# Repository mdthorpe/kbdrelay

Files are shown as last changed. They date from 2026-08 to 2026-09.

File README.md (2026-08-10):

# kbdrelay — USB HID keyboard bridge

A transparent two-board bridge that lets any USB keyboard type into a target
device as if it were a plain USB 1.1 boot-protocol keyboard. Two cheap
single-USB-controller boards, joined by a short SPI harness.

- **KBD** — keyboard-facing board (USB **host**, SPI **master**). The keyboard
  plugs into it; it reads key events and forwards them.
- **TGT** — target-facing board (USB **device**, SPI **slave**). It plugs into
  the target machine and presents as a vanilla boot keyboard, replaying what
  KBD sends.

> Boards are named for what they face. "Sender/receiver" is banned vocabulary
> here — both boards send and receive over the bidirectional SPI link.

See [`spec.md`](spec.md) (what/why), [`plan.md`](plan.md) (how), and
[`tasks.md`](tasks.md) (build log / progress).

## Status

**v1 achieved on the bench** — typing crosses the bridge, Caps/Num Lock LEDs
round-trip, hot-plug recovers, and the whole chain was validated on a
**Commodore Amiga 1200 (1992)** via a USB keyboard adapter, with modern and
vintage keyboards. Verified: AC1–AC5 (see `tasks.md` for caveats).

## Hardware

- 2× **Waveshare ESP32-S3-Zero** (one KBD, one TGT).
- Onboard WS2812 status LED (GPIO21, **RGB** order).
- Power: KBD from a dedicated 5 V feed (bus power / USB-PD); TGT from the target
  machine's USB. **Grounds common; 5 V never merged** (FR5).
- Keyboard-power inrush needs a **bulk cap (~220–1000 µF) on KBD's 5 V**.

### SPI harness (wire same-name to same-name — SPI names encode direction)

| Signal | KBD (master)  | TGT (slave) | Notes |
|---|---|---|---|
| SCK | GPIO4 (GP4) | GPIO4 | 1 MHz |
| MOSI | GPIO5 (GP5) | GPIO5 | key reports, heartbeats → |
| MISO | GPIO6 (GP6) | GPIO6 | ← LED reports |
| CS | GPIO7 (GP7) | GPIO7 | |
| DATA_READY  | GPIO8 (in) | GPIO8 (out) | TGT signals a queued LED report |
| GND | GND | GND | common |

Put **~470 Ω (→2.2 kΩ recommended) in series** on each signal line — limits
backfeed between boards when one is unpowered (FR5.4) and tames ringing.

## Firmware

ESP-IDF **6.x** via **PlatformIO** (`framework = espidf`). Shared framing +
CRC lives in [`components/bridge_proto`](components/bridge_proto) (also unit-
tested on the host). One project, one env per firmware:

| env | board role | what it is |
|---|---|---|
| `kbd` | KBD | USB host → reads keyboard → SPI master forwards KEY_REPORTs |
| `tgt` | TGT | SPI slave → replays as boot keyboard; watchdog releases keys |
| `mock_kbd` | test | SPI-master stand-in (scaffold) |
| `mock_tgt` | test | SPI-slave stand-in (scaffold) |
| `native` | host | `bridge_proto` unit tests (no hardware) |

### SPI protocol

Fixed 12-byte frames, full-duplex: `SYNC(0xA5) TYPE SEQ PAYLOAD[8] CRC8`.
Types: `IDLE`, `KEY_REPORT` (KBD→TGT), `LED_REPORT` (TGT→KBD), `HEARTBEAT`.
KBD sends on key change or every 25 ms; TGT releases all keys if no valid frame
for 75 ms (FR4.1).

## Build / flash / test

```sh
make build ENV=kbd        # compile (kbd | tgt | mock_kbd | mock_tgt)
make upload ENV=kbd       # flash over USB-C (see flashing quirks below)
make monitor              # serial monitor on the USB-UART adapter
make test                 # host unit tests (native, no hardware)
make reconfigure ENV=kbd  # clean rebuild of one env
```

Toolchain: PlatformIO Core (Python 3.13 penv) + ESP-IDF 6.x, board def
`boards/waveshare_esp32_s3_zero.json` (the official platform doesn't ship it).

### S3-Zero flashing quirks

- **Download mode:** hold **RESET + BOOT**, release RESET, pause, release BOOT.
- **After flashing, physically reset** (unplug/replug or RESET) — a software
  reset over native USB does not boot the app.
- **Logs go over UART** (TX/RX pads, 3.3 V USB-UART adapter, 115200): the USB-C
  is used by the app (host on KBD, device on TGT), and USB-Serial/JTAG shares
  the S3's USB PHY. Console is forced to UART (`CONFIG_ESP_CONSOLE_UART_DEFAULT`).
- **Power-up order on the bench:** power TGT (into the target) before KBD.

## License

TBD.

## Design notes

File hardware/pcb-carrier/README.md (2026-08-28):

# kbdrelay carrier board (hardware)

Single-sided, through-hole KiCad carrier PCB that hosts two socketed Waveshare
ESP32-S3-Zero modules (KBD + TGT) and joins them into the kbdrelay bridge.

**v0.1 is shipped and hardware-verified** (tag `v0.1-board`). The
`pcb-carrier-board` spec is **closed as the v0.1 record** — do not amend it.
New work happens in the v0.2 spec.

| What | Where |
|---|---|
| **Board of record (v0.1, as etched)** | `kbdrelay-carrier/kbdrelay-carrier-v0.1.kicad_pcb` — hand-routed, 0 DRC errors, zero jumpers |
| Schematic (shared by both layouts) | `kbdrelay-carrier/kbdrelay-carrier.kicad_sch` — ERC clean |
| Superseded scripted layout | `kbdrelay-carrier/kbdrelay-carrier.kicad_pcb` — ⚠ 4 DRC errors, still has the dropped LED. **Never export fab output from it.** |
| v0.1 retrospective | [`RETRO-v0.1.md`](./RETRO-v0.1.md) |
| v0.1 spec (closed) | [`../../.specs/pcb-carrier-board/`](../../.specs/pcb-carrier-board/) |

## Layout / conventions

```
hardware/pcb-carrier/
├── kbdrelay-carrier/
│   ├── kbdrelay-carrier.kicad_sch          # the schematic (one, shared)
│   ├── kbdrelay-carrier-v0.1.kicad_pcb     # BOARD OF RECORD (hand-routed)
│   ├── kbdrelay-carrier-v0.1.kicad_pro
│   ├── kbdrelay-carrier.kicad_pcb/.kicad_pro  # superseded scripted layout
│   ├── symbols/kbdrelay.kicad_sym          # project-local symbols (S3-Zero)
│   ├── footprints/kbdrelay.pretty/         # project-local footprints (.kicad_mod)
│   └── sym-lib-table / fp-lib-table        # register the above via ${KIPRJMOD}
├── fab/gerbers/                            # kbdrelay-carrier-v0.1-*.gbr (as etched)
├── place.py / route.py                     # scripted layout (superseded by hand route)
├── bridge_risk.py / audit_gaps.py          # etch-gap audits
├── make_lcd_art.sh                         # LCD photoresist artwork
├── BOM.md                                 # bill of materials
├── BUILD.md                               # fab + assembly + bring-up notes
└── RETRO-v0.1.md                          # what v0.1 taught us
```

- Use **project-local libraries** (Project-scope in KiCad) so the design is
  self-contained for anyone who clones the repo.
- Board is **single copper layer** (bottom), all discretes **through-hole**.
  Jumper-link budget was ≤ ~8; **v0.1 shipped with zero** — the hand route needed
  none, at wider traces (1.0 mm) than the script ever managed.
- Firmware is unchanged from v1 (same S3-Zero pinout: SPI GP4–GP8, USB on the
  module USB-C, UART0 TX/RX pads, WS2812 on GPIO21).

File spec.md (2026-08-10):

# Spec: USB HID Keyboard Bridge

**Status:** Draft v0.3 · **Level:** Functional (what/why — no implementation choices here)

## Naming

- **KBD** — the keyboard-facing board. USB host; the keyboard plugs into it.
  (Formerly "receiver.")
- **TGT** — the target-facing board. USB device; it plugs into the target
  machine and presents as a keyboard. (Formerly "sender.")

Boards are named for what they face, which never inverts. "Sender/receiver"
is banned vocabulary in this project: both boards send and receive on the
bidirectional SPI link, so those words are ambiguous.

## Overview

A transparent two-board bridge that lets any USB keyboard type into a target
device as if it were a plain USB 1.1 boot-protocol keyboard.

- **KBD** reads key events from the keyboard and forwards them over SPI.
- **TGT** replays those events to the target as a minimal boot-protocol
  keyboard.

Primary motivation: two cheap single-USB-controller boards are simpler and
more cost-effective than one board with dual USB controllers, and the split
makes each half independently developable and testable.

## Constitution (project principles)

1. Cheapest commonly available parts that meet requirements; no unused capability.
2. Each board is independently developable and testable (SPI peer can be mocked).
3. Prefer boring, well-documented libraries and stacks over clever code.
4. Artifacts stay proportional to the problem: one spec, one plan, one task list.

## Functional Requirements

### FR1 — Keyboard input (KBD)
- **FR1.1** Accept exactly one USB keyboard, plugged directly into KBD.
- **FR1.2** Keyboards that internally enumerate as a hub + HID device MUST work.
  KBD's host stack must traverse one hub level to reach the keyboard
  interface. (Many modern keyboards are internally hub devices.)
- **FR1.3** Boot-protocol keyboard support (8 modifiers + 6-key rollover) is the
  fidelity bar. NKRO, media keys, and vendor extensions are out of scope; if a
  keyboard offers boot protocol, use it.
- **FR1.4** Keyboard hot-plug MUST work: unplug/replug at any time without
  restarting either board.

### FR2 — Bridge link (SPI)
- **FR2.1** Key events are forwarded KBD → TGT over SPI.
- **FR2.2** The link is bidirectional: HID output reports (LED state — Caps/Num/
  Scroll Lock) flow TGT → KBD and MUST reach the keyboard, so lock LEDs
  reflect the target's state.
- **FR2.3** Messages carry a type identifier. v1 defines types for (a) keyboard
  input report and (b) LED output report. The framing MUST allow new types to be
  added without breaking existing ones (future: synthetic/custom key events —
  see Design Considerations).
- **FR2.4** Message integrity MUST be verifiable (e.g., checksum); corrupt
  messages are dropped, never replayed as keystrokes.

### FR3 — Keyboard output (TGT)
- **FR3.1** TGT presents to the target as the most vanilla USB low-speed
  boot-protocol keyboard possible: single interface, no composite device, no
  extra endpoints. Reference bar: works on hosts that support only USB 1.1-era
  keyboards.
- **FR3.2** Reports from KBD are replayed transparently — no remapping,
  no filtering, no reordering.

### FR4 — Failure behavior
- **FR4.1** On keyboard disconnect, SPI link loss, or KBD power loss, TGT
  MUST release all keys (send an empty report) within **100 ms**. No
  stuck keys, ever.
- **FR4.2** Either board MUST tolerate the other being unpowered or absent
  indefinitely, and recover automatically when it returns.
- **FR4.3** TGT remains enumerated on the target even when the keyboard
  or KBD is absent — it never disconnects/reconnects on the USB bus, it
  simply types nothing. (To the target: a keyboard nobody is touching. Distinct
  from FR2.4, which governs dropping corrupt messages.)

### FR5 — Power
- **FR5.1** Each board has exactly ONE 5 V source, and two sources are never
  connected together. KBD is powered from a dedicated power-only USB feed
  ("bus power"). TGT is powered solely by the target machine's USB port.
- **FR5.2** KBD MUST supply 5 V VBUS to the keyboard port, with ≥ 250 mA
  guaranteed (covers any conventional keyboard). Power is routed through the
  dev board's normal power path (onboard connector); the actual ceiling
  therefore depends on the board's power-path components and MUST be
  documented in plan.md. High-draw RGB keyboards at full brightness are
  best-effort. (Future option: USB-C PD supply and/or direct-rail feed can
  raise the budget without spec changes.)
- **FR5.3** TGT receives VBUS from the target device; this MUST NOT backfeed
  into or conflict with bus power. The target's port is never asked to power
  anything beyond TGT itself (tens of mA).
- **FR5.4** Boards share ground via the SPI harness (all grounds in the
  system are common). Driving SPI lines into an unpowered peer MUST NOT
  damage or latch up either board.

### FR6 — Latency
- **FR6.1** Added end-to-end latency (keyboard event received by KBD →
  report available to target) ≤ **10 ms**, excluding USB polling intervals
  outside our control. Human typing speed is the use case; gaming is not.

## Out of Scope (v1)

- External hubs / multiple keyboards / mouse or other HID device classes
- NKRO, media keys, consumer-control pages, vendor-specific HID
- Key remapping, macros, synthetic events (noted below as a design consideration)
- Wireless anything
- Configuration UI of any kind

## Design Considerations (non-binding, informs plan.md)

- **Future synthetic events:** a later version may inject target-specific
  combinations (e.g., Fn+Key unique to the target device). FR2.3's typed message
  framing exists so this can be added as a new message type with no protocol
  break. Do not otherwise design for it.
- **SPI direction asymmetry:** SPI is master/slave and the slave cannot initiate
  transfers. The LED backchannel (FR2.2) will need a data-ready signal line or
  polling; the spec requires the behavior, not the mechanism.

## Acceptance Criteria

- **AC1** A plain boot-protocol keyboard and a hub-type keyboard both type
  correctly into the target, including modifiers and 6-key chords.
- **AC2** Caps Lock pressed on the keyboard toggles the target's caps state AND
  the keyboard's Caps Lock LED.
- **AC3** Holding a key and yanking the keyboard (or the SPI harness, or KBD
  power) releases the key on the target within 100 ms.
- **AC4** Keyboard replug and KBD power-cycle both recover to a working
  state with no interaction on the TGT/target side.
- **AC5** TGT enumerates and types correctly on a USB 1.1-era reference
  target.
- **AC6** Each board passes its tests standalone with the SPI peer mocked.

## Open Questions

- ~~Name a specific reference target device for AC5?~~ **RESOLVED:** v1 was
  validated against a **Commodore Amiga 1200 (1992) with a USB keyboard
  adapter**, using both modern and vintage USB keyboards. If a machine of that
  era accepts TGT, the boot-keyboard descriptor is effectively universal.

## Observations (v1 bring-up)

- **Numpad on nav/symbol keys (target-side limit):** numpad-only keyboards
  produce digits with Num Lock on, but the navigation/math-symbol *Keypad*
  usages don't reach the Amiga. HID keypad keys always send Keypad usages; the
  *host* maps them to digits vs arrows per Num Lock. The bridge replays
  keycodes verbatim (FR3.2), so this is the target adapter's interpretation,
  not a bridge fault. A future synthetic-event type (see Design Considerations)
  could remap if ever desired.

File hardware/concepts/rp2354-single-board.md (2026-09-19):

# Concept: single-board RP2354 kbdrelay

**Status: CONCEPT / SCRATCH — PARKED. Not a spec. No gates, no approvals, not
tracked in `.specs/`.**

> **Parked 2026-09-XX.** Assorted RP2350 dev boards ordered (see §7) to try the
> firmware path. Pick this back up when they arrive — start at §8 step 1.
> The active hardware effort remains `.specs/pcb-carrier-v0-2/`.
 This is a "what would we build with no inherited requirements"
sketch from a discussion on 2026-09-XX. Nothing here supersedes
`.specs/pcb-carrier-v0-2/`, which remains the real, active effort.

---

## 1. Premise

Throw away every constraint the current design inherited — two boards, an SPI
link, THT parts, home etching, the ESP32-S3 — and ask what the device actually
wants to be. Answer: **one chip, one board, no inter-board protocol.**

The ESP32-S3 forced the two-board architecture because it has a single USB OTG
controller: it can be host *or* device, not both. The RP2040/RP2350 family has a
hardware USB controller **plus** PIO, and `pico-pio-usb` bit-bangs a second
full-/low-speed USB port out of PIO state machines. One chip, two USB ports, no
bridge protocol at all.

### What this deletes

| Gone | Why |
|---|---|
| Second MCU | one chip has both PHYs |
| SPI link (SCK/MOSI/MISO/CS/DATA_READY) | no inter-board comms |
| 12-byte framing + CRC8 | ditto |
| 2.2 kΩ series resistors ×5 | ditto |
| Open-drain CS backfeed workaround | one rail, no peer to backfeed |
| Power-sequencing failure class entirely | one rail |
| Reverse-polarity Schottky D1 + its unmeasured ~0.3 V Vf | USB-C can't be reversed |
| PPTC F1 | replaced by an active current-limit switch |
| 470 µF bulk inrush cap | replaced by the switch's soft-start |
| UART console + BOOT/RESET flashing ritual | UF2 mass-storage bootloader |

### What it costs

A firmware rewrite, against a different USB stack, replacing code that is
verified on real hardware including a 1992 Amiga 1200. The bridge logic itself
is trivial (TinyUSB host HID → shared report buffer → TinyUSB device HID, ~300
lines), but the **descriptor-parsing keyboard detection** and **report dedup**
logic were paid for in bench time and have to be re-earned.

---

## 2. Core architecture (shared by both variants)

```
                  ┌──────────── RP2354A ────────────┐
 USB-A recept.    │                                 │   captive USB-A
 (keyboard)  ─────┤ PIO-USB host      native USB dev ├────── pigtail
   D+/D-          │ (2 consecutive     (hardware PHY)│       (target)
                  │  GPIO, 27R + 15k)               │
                  └─────────────────────────────────┘
```

**PHY assignment is deliberate and non-negotiable:** the *target* side gets the
hardware USB controller, because that is the side that must present as a
bulletproof vanilla USB 1.1 boot keyboard to a 1992 machine via an adapter. The
*keyboard* side gets PIO-USB, because that peer is swappable and observable.

**MCU: RP2354A** — RP2350 with 2 MB flash stacked in package. Drops the external
QSPI flash IC and its four routed traces. Dual Cortex-M33, 12 PIO state
machines. RP2040 + W25Q16 works identically and is ~$0.30 cheaper; RP2354A is
chosen for fewer parts and because learning the current chip is worth more than
learning the five-year-old one.

**Signal integrity:** this is USB **full speed, 12 Mbps**, rise times ~4–20 ns.
Controlled-impedance 90 Ω differential pairs and a 4-layer stackup are
*optional practice*, not a requirement. Every cheap USB dongle on earth is
2-layer. Keep pairs short, roughly matched, over unbroken ground, and stop
worrying. Hand-soldered pigtails are electrically fine at FS.

**Common parts:**

| Ref | Part | Note |
|---|---|---|
| U1 | RP2354A (QFN-60, 7×7) | 2 MB stacked flash |
| Y1 | 12 MHz crystal, 3225 | PIO-USB needs a 120/240 MHz sysclk multiple |
| U2 | AP2112K-3.3 LDO | MCU only, ~50 mA |
| U3 | TPS2051C / MIC2005 | keyboard-port current limit, soft-start, FAULT |
| D1,D2 | USBLC6-2SC6 ×2 | ESD, both ports |
| D3 | WS2812B | status; light pipe in the case |
| SW1,SW2 | BOOTSEL, RESET | pinholes in the case bottom |
| J1 | USB-A receptacle | keyboard |
| — | Tag-Connect TC2030 pads | SWD, underside |
| — | 2× UART test pads | console via CH340 dongle |
| — | 0402 passives | |

**Debug:** BOOTSEL gives UF2 drag-and-drop flashing over the native USB port —
unplug from the target, plug into a laptop, hold one button, drag a file. No
UART dance, no physical power-cycle. The USB CDC console is **not** available,
because the native port is busy being a keyboard and adding a composite CDC
interface would break the "vanilla boot keyboard" contract the Amiga adapter
depends on. Hence the UART pads, and hence SWD being worth the footprint —
stepping through TinyUSB enumeration beats printf by a wide margin.

**GPIO budget** is not close to tight: 2 for PIO-USB D+/D−, 1 VBUS sense, 1
TPS2051 EN, 1 FAULT, 1 WS2812, 2 UART, 1 mode strap, SWD dedicated. Break out 8
spare on a castellated edge or 1.27 mm header anyway.

---

## 3. Variant A — externally powered puck

**The chosen primary concept.**

### Power

```
USB-C 5V (5.1k CC pulldowns) ─┬─ AP2112K-3.3 ── RP2354A
                              └─ TPS2051C ───── USB-A VBUS (keyboard)

target VBUS ── divider ── GPIO   (SENSE ONLY, zero draw)
target D+/D-/GND ─────────────── native USB
```

The target side is a **self-powered USB device**: it takes D+/D−/GND and senses
VBUS through a divider, drawing exactly nothing from the target. Descriptor
reports self-powered, `bMaxPower = 0`.

⚠ **The one rule:** do not assert the D+ pull-up until VBUS is detected. Assert
it early and you back-power the host's bus through the pull-up, and the target
sees a phantom device while it's powered off. RP2350's native USB has VBUS
detect and TinyUSB handles this — it's a config item, not a design problem.

This is what makes the entire v0.1 backfeed saga (the 1.68 V latch, the
open-drain CS fix, the rejected bleeder resistors) structurally impossible:
there is one rail, and the target contributes nothing to it.

USB-C input over a barrel jack because it can't be inserted backwards (deleting
D1 and its Vf penalty), every phone charger is a valid supply, and 5.1 kΩ CC
pulldowns let you read the advertised current if you ever care.

Keyboard-port current limit can be set generously (~1.2–1.5 A) since the supply
is external. The TPS2051C's controlled slew-rate soft-start is the *correct*
fix for the high-inrush-keyboard brownout that the 470 µF cap was papering over,
and its FAULT pin gives a deterministic failure: LED goes red, log says
"keyboard exceeded limit", firmware can retry by toggling EN.

### Form factor

~45 × 30 × 12 mm block, two-part 3D-printed case, four M2 heat-set inserts.

- **Front edge:** USB-A receptacle (keyboard).
- **Rear edge:** captive USB-A male pigtail to target, plus USB-C power jack.
  Both cables leave rearward; the keyboard sits clean in front.
- **Front face:** RGB LED behind a light pipe.
- **Bottom:** BOOTSEL/RESET pinholes, SWD pads.

Silhouette matches the period-correct Amiga/PS2/ADB adapter dongles, which is
half the appeal. It reads as a piece of kit, not a dev board in a box.

**Pigtail assembly is self-service** — PCBWay won't attach cables. Put a 4-pad
2.54 mm footprint at the board edge with two slots either side for a zip-tie
strain relief; cut the end off a USB-A extension cable and solder
D+/D−/VBUS-sense/GND. A 4-pin JST-PH hidden inside the case is the detachable
alternative. Budget ~10 minutes and one moment of regret.

### Cost

BOM ~$4.50. Five assembled boards from PCBWay including setup/stencil/
engineering: **$120–150 total**, i.e. $25–30 each. Setup fees dominate at this
quantity; at qty 50 it'd be $10–15 each.

### Trade-off

Three cables. That's the honest cost of the always-externally-powered choice —
it buys total immunity from the power-sequencing bug class and unlimited
keyboard headroom, and it pays in desk clutter and a board that's dead without
a brick.

---

## 4. Variant B — 500 mA bus-powered stick

**Worth building too. Prettier object, tighter constraints.**

Drop the USB-C jack entirely. The whole device runs from the target's VBUS.

### Power

```
target VBUS ─┬─ AP2112K-3.3 ── RP2354A   (~40 mA)
             └─ TPS2051C ────── USB-A VBUS (keyboard, limit ~400 mA)
```

Now a **bus-powered** device: descriptor declares `bMaxPower = 250` (500 mA),
and it must draw ≤100 mA until configured — which it does comfortably, since
the bridge itself is ~40 mA and the keyboard port stays disabled (TPS2051 `EN`
low) until enumeration completes. That gating is mandatory, not optional.

### Power budget

| Load | Current |
|---|---|
| RP2354A @ 120 MHz + PIO-USB | ~35–40 mA |
| WS2812B (dim / single colour) | ~5–20 mA |
| Regulator + leakage | ~5 mA |
| **Available for keyboard** | **~430 mA** |

Reality check on what that covers:

| Device | Typical draw | Works? |
|---|---|---|
| Vintage / membrane keyboard | 20–50 mA | yes, trivially |
| Modern mechanical, no backlight | 50–100 mA | yes |
| Single-colour backlit | 100–250 mA | yes |
| RGB gaming keyboard | 300–500 mA | marginal to no |
| Keyboard with integrated USB hub | 500 mA+ | no |
| Game controller with rumble | 500 mA spikes | no |

So: **~80% of devices, and the excluded 20% is knowable in advance.** Set the
TPS2051C limit to ~400 mA with its ILIM resistor. A device over budget trips the
switch, FAULT asserts, LED goes red — a clean refusal at plug-in, not a
brownout thirty minutes into a session. That deterministic failure mode is the
entire reason the active switch is worth $0.40 over a PPTC.

**Open risk:** the target must actually supply 500 mA. A modern PC will. A 1992
A1200 via a USB-to-Amiga adapter is an unknown — depends entirely on that
adapter's regulator, and the A1200's own supply is a beefy linear unit so the
upstream side is probably fine. **This is the thing to measure first if Variant
B gets built.**

### Form factor

~35 × 18 × 10 mm — genuinely a USB stick. USB-A receptacle one end, captive
USB-A male pigtail the other (or a board-edge male plug, which needs a 2.0–2.4
mm board or a shim and turns it into something rigid hanging off the machine —
the pigtail is more practical). Two cables total, no brick, nothing to plug in.

### Cost

BOM ~$3.80. Same assembly economics as A.

### Trade-off

More elegant object, one fewer cable, no wall wart — and a device that silently
excludes a whole class of modern keyboards, plus an unverified assumption about
what the target port can source.

---

## 5. Variant comparison

| | A: externally powered | B: bus-powered |
|---|---|---|
| Cables | 3 (keyboard, target, power) | 2 |
| Size | ~45 × 30 × 12 mm puck | ~35 × 18 × 10 mm stick |
| Keyboard budget | ~1.2 A, essentially unlimited | ~430 mA |
| RGB / hub keyboards | yes | no |
| Works without a brick | no | yes |
| Unverified assumptions | none material | target port sources 500 mA |
| BOM | ~$4.50 | ~$3.80 |
| Failure mode | none expected | clean refusal via FAULT |

They share ~90% of the schematic. Building A first and B second is cheap;
building both in one PCBWay order is cheaper still, and directly answers the
"can the A1200 adapter actually feed this" question with hardware.

---

## 6. Deliberately excluded

**Full HID dev/lab tool** (capture, replay, descriptor dumping, protocol
fuzzing, OLED, broken-out GPIO banks). Products already exist for this. Not
worth building.

**Still open, and cheap to defer:** transparent-only versus a compiled-in
keymap remap table. Pure firmware. The interesting version is **layout
translation** — the Amiga adapter maps HID usages to Amiga scancodes
positionally, so a modern PC keyboard puts the wrong keys in the wrong places;
remapping in the bridge makes any keyboard an Amiga keyboard with no adapter
changes. Hardware cost is one GPIO mode strap, or just reuse BOOTSEL as a
runtime input. Wire the strap regardless and decide after the board boots.

---

## 7. Off-the-shelf shortcut — Waveshare RP2350-USB-A

**Found 2026-09-XX. This may make Variant B a firmware-only project.**

<https://www.waveshare.com/rp2350-usb-a.htm> — RP2350A, 2 MB flash, LDO 500 mA,
listed as *"with PIO-USB Type-A and USB Type-C port"*. Under $10. That is a
native USB device port **and** a PIO-USB Type-A host receptacle on one
off-the-shelf board — i.e. the entire Variant B topology, already built.

The PHY assignment falls out correct: **native hardware USB on the Type-C →
target** (via a C-to-A cable), **PIO-USB on the Type-A receptacle → keyboard**.
That matches §2's non-negotiable split exactly.

Sibling products, for reference:

| Board | Ports | Fit |
|---|---|---|
| **RP2350-USB-A** | PIO-USB Type-A host + native Type-C | **the one** |
| RP2350-USB-C (`sku=34641`/`34953`) | PIO-USB on a Type-C, female or male | needs an A-to-C adapter for the keyboard; worse for no gain |
| RP2350-One | Type-A male, single port | USB-stick form factor, only one port |
| RP2350-PiZero | native Type-C + PIO-USB port + DVI/TF | works, but far more board than needed |

**RP2354 is a non-issue here.** Stacked flash was only ever a part-count
optimisation on a board *we* lay out. On a module someone else assembled, an
external W25Q is two parts we never touch.

### Check these on the schematic PDF before ordering

These decide whether "add external power" is a jumper or a trace cut:

1. **Is the Type-A port's VBUS tied straight to Type-C VBUS, with any current
   limit?** Almost certainly a direct tie with no limiting. That means a greedy
   keyboard browns out the MCU — precisely the failure the TPS2051C exists to
   prevent. Fine for an experiment, not for a thing you actually use.
2. **Is there a broken-out 5 V/VBUS pad, and a diode between it and the
   Type-C?** If there's no diode, injecting external 5 V there **back-drives
   VBUS onto the target's port** — the exact bug class v0.1 spent months on.
   Adding external power would mean cutting the VBUS trace and feeding
   downstream of the cut. Doable, ugly, and it turns a clean dev board into a
   bodge.
3. **CC pulldowns on the Type-C.** Near-certain since it's a device port, but
   confirm if the plan is ever to power it from a charger.

No ESD protection on either port, obviously. Irrelevant at this price.

### Consequence for this concept

Buy one and prove the firmware first (see §8). If it works and 500 mA covers
the keyboards you care about, **you may simply be done** and never need a
custom board at all. If the power ceiling bites, the answer is the custom
Variant A board — *not* a VBUS bodge on a dev board.

---

## 8. Breadboard / prototyping path

Nothing here needs a fabbed board to validate. The whole architecture can be
proven on off-the-shelf parts first, and **should be** — specifically the
PIO-USB hub and low-speed handling, which is where the bring-up risk is
concentrated.

Cheapest credible rigs, roughly in order of convenience:

| Option | What it is | Note |
|---|---|---|
| **Waveshare RP2350-USB-A** | RP2350 + PIO-USB Type-A host + native Type-C | see §7 — this *is* Variant B, not just a rig for it |
| Adafruit Feather RP2040 **with USB Type A Host** (#5723) | RP2040 + a real USB-A host port already wired to PIO with the 27 Ω/15 k network | closest thing to the concept in a dev board; just add power |
| Adafruit RP2040/RP2350 board + **USB Host BFF / Stemma host breakout** | host port as an add-on | flexible, works with RP2350 for the actual target chip |
| Pico 2 (RP2350) + USB-A breakout + 2× 27 Ω + 2× 15 kΩ | fully manual | cheapest, ~$8 total, and you learn the host-port network properly |
| Waveshare RP2040-PiZero | has a USB-A host port | fine, less documented for PIO-USB |

Software: `pico-pio-usb` + TinyUSB, either the Pico SDK directly or the Arduino
core (`arduino-pico` bundles both and has working host-HID examples). Validate
in this order:

1. Enumerate one plain keyboard over PIO-USB, print reports to UART/SWD.
2. Simultaneously present as a boot keyboard over native USB to a laptop.
3. Pass keystrokes end to end. This is the whole product.
4. **Low-speed keyboard** over PIO-USB (the vintage ones).
5. **Hubbed / composite keyboard** — the known-weak case.
6. Measure actual current draw of the bridge, and of each keyboard you own, to
   settle Variant B's budget with numbers instead of a table of guesses.
7. If an A1200 is to hand: measure what the USB adapter will source. That single
   number decides whether Variant B is real.

Only after 1–5 pass is there any point ordering a board.

---

## 9. Provenance

Discussion-only, outside the spec process, at the user's explicit request. The
active hardware effort remains `.specs/pcb-carrier-v0-2/` (two-board ESP32-S3
carrier, PCBWay 2-layer, THT discretes, 3D-printed case). Nothing in this file
is approved, gated, or scheduled.

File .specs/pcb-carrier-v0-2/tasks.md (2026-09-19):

# PCB Carrier Board v0.2 Tasks

Spec: `pcb-carrier-v0-2`  
Status: tasks-draft  
Created: 2026-08-29  
Brainstorm: `./brainstorm.md`
Requirements: `./requirements.md`
Design: `./design.md`

## Implementation Plan

Ordered PCB tasks, each traceable to requirement IDs, each with a concrete
"done when". New KiCad project at `hardware/pcb-carrier-v0.2/`; **no v0.1 file is
touched** — v0.1 is frozen at tag `v0.1-board`.

> ⚠ **T-002 is a hard gate on T-005.** Per design decision D-004, the power-path
> measurement happens on a breadboard **before** layout, not at bring-up. If it
> fails, the correct response is to return to the design gate — or the
> requirements gate if the fix is a supply above 5.00 V, which contradicts D-003.
> Do not begin layout on the strength of the budget arithmetic alone. That is
> exactly the mistake v0.1 made (retro F-8).

- [ ] 1. Project, design rules, and libraries
  - ID: T-001
  - Requirement(s): NFR-001, NFR-002, NFR-006, NFR-011
  - Files/areas: `hardware/pcb-carrier-v0.2/` (new KiCad project),
    `kbdrelay-carrier-v0.2.kicad_dru`, `sym-lib-table`, `fp-lib-table`
  - Work: create the KiCad project with version in the filename; vendor
    PCBWay's rules as the project-local `.kicad_dru` with the **2-layer 1 oz**
    rule block active and the others left commented; set board stackup to
    2 layers; register the project-local S3-Zero symbol/footprint library.
    Confirm the seven stock footprints named in design.md resolve.
  - Validation: `kicad-cli pcb drc` runs and *enforces* the vendored rules —
    prove enforcement with a temporary canary rule that must fail, then remove
    it. A rules file that silently fails to load is worse than none.
  - Done when: empty board DRCs clean against PCBWay rules, canary proved
    enforcement, all footprint references resolve.

- [ ] 2. **GATE** — Breadboard power-path validation
  - ID: T-002
  - Requirement(s): FR-013, FR-014, FR-017, FR-018, NFR-014
  - Files/areas: bench; results recorded in `design.md` and
    `hardware/pcb-carrier-v0.2/MEASUREMENTS.md`
  - Work: build `J1 → F1 → D1(shunt) → C1/C2 → module VDD` on a breadboard with
    the real parts. At **exactly 5.00 V** input and a **500 mA** load at the
    keyboard port, measure and record all three: voltage at the jack, at
    U1.VDD, and at keyboard VBUS. **The unknown being measured is the module's
    internal VDD→VBUS drop** — the ~0.255 V of budget nobody has ever checked.
    Then: apply reverse polarity and confirm D1 conducts, F1 trips, and normal
    operation resumes once corrected with nothing replaced. Also confirm a
    high-inrush keyboard enumerates first try with C1 fitted.
  - Validation: keyboard VBUS ≥ 4.40 V at 500 mA from 5.00 V in, **measured and
    written down**, not inferred.
  - Done when: the measurement is recorded and either (a) VBUS ≥ 4.40 V, so
    layout may proceed, or (b) it is short, and the fallback chain in design.md
    §Risks is worked in order — swap F1 to Littelfuse 60R090 for +0.055 V, else
    return to the requirements gate on D-003. **Recording a failure and
    proceeding anyway is not an acceptable outcome.**

- [ ] 3. Schematic capture
  - ID: T-003
  - Requirement(s): FR-006, FR-007, FR-008, FR-011, FR-012, FR-015, FR-020,
    FR-021, FR-022, NFR-004, NFR-007
  - Files/areas: `hardware/pcb-carrier-v0.2/kbdrelay-carrier-v0.2.kicad_sch`
  - Work: capture the net list in design.md §Schematic Design exactly. All five
    SPI lines through R1–R5 on the GP4–GP8 mapping; common GND; power chain
    J1→F1→D1→C1/C2→U1.VDD with D1 as a **shunt** (cathode to rail, anode to
    GND) and F1 **upstream** of D1; both UART headers through R6–R9 with **no
    supply pin**; **U2.VDD carrying an explicit no-connect flag** so ERC records
    the 5 V isolation as intentional. Every part gets a value and a footprint.
  - Validation: `kicad-cli sch erc` → **zero violations** (AC-10, ERC half).
  - Done when: ERC is clean, U2.VDD is explicitly no-connect, and no net joins
    the two 5 V domains.

- [ ] 4. BOM and sourcing verification
  - ID: T-004
  - Requirement(s): NFR-004, NFR-005, NFR-006
  - Files/areas: `hardware/pcb-carrier-v0.2/BOM.md`
  - Work: generate the BOM from the schematic. For each of the twelve
    non-module line items, confirm the MPN is **currently in stock at one
    distributor** and record the ordering part number. Confirm every part is
    through-hole and that only the module uses a hand-built footprint.
  - Validation: a single cart at one distributor covers every non-module line
    item (AC-12).
  - Done when: BOM is generated from the schematic rather than hand-written,
    every MPN is confirmed orderable, and any substitution is recorded.

- [ ] 5. Two-layer layout *(blocked by T-002)*
  - ID: T-005
  - Requirement(s): FR-003, FR-004, FR-016, NFR-002, NFR-003, NFR-008, NFR-016
  - Files/areas: `hardware/pcb-carrier-v0.2/kbdrelay-carrier-v0.2.kicad_pcb`
  - Work: place U1/U2 at opposite board edges with USB-C over the 1.5 mm
    overhang notch; J1 on the front edge near U1; power cluster between them;
    R1–R5 mid-board. Route **signals on F.Cu only**, leaving **B.Cu as an
    uninterrupted ground pour** — the structural fix for v0.1's split pour.
    Minimise outline subject to iron access (NFR-003 vs NFR-016; NFR-016 wins).
    Silkscreen `5V ⏜ centre +` at J1, plus the version identifier. Verify
    nothing obstructs either module's BOOT/RESET buttons.
  - Validation: `kicad-cli pcb drc` against the vendored PCBWay rules → **zero
    violations** (AC-10, DRC half); a `pcbnew` script fills zones and asserts
    the GND net resolves to **exactly one** connected region with zero
    unconnected items (AC-11).
  - Done when: DRC clean, ground verified as a single region **by script and not
    by eye**, buttons unobstructed, outline measured and recorded.

- [ ] 6. Fabrication package and build documentation
  - ID: T-006
  - Requirement(s): NFR-010, NFR-011, NFR-012, NFR-013
  - Files/areas: `hardware/pcb-carrier-v0.2/fab/`, `BUILD.md`, `README.md`,
    an as-built extraction script
  - Work: export Gerbers and drill to **exactly one** canonical directory, with
    the version in every filename. Write `BUILD.md` for a builder with no prior
    knowledge: order, assemble in a stated sequence, bring up, and how to tell
    it works. Write the script that extracts the as-built table (outline, track
    widths, clearances, layer count, footprint count) **from the board file**, so
    no as-built number is ever restated by hand (NFR-013).
  - Validation: Gerbers render correctly in an independent viewer; the as-built
    script output matches the board; no fab output exists anywhere else in the
    tree.
  - Done when: the package is orderable without opening KiCad, and every
    as-built figure in the docs is script-generated.

- [ ] 7. Order and assemble
  - ID: T-007
  - Requirement(s): FR-002, NFR-005, NFR-016
  - Files/areas: physical hardware; notes to `BUILD.md`
  - Work: order boards from PCBWay and parts from the verified BOM. Assemble
    following `BUILD.md` **as written**, recording every place the
    documentation was wrong or insufficient.
  - Validation: assembly completes with no undocumented step; every joint was
    reachable with a conventional iron with neighbours already fitted (AC-15).
  - Done when: at least one board is populated, `BUILD.md` is corrected from
    real experience, and any NFR-016 violation is recorded even if tolerable.

- [ ] 8. Bare-board bring-up *(no modules seated)*
  - ID: T-008
  - Requirement(s): FR-007, FR-008, FR-012, FR-013, FR-014, FR-015, NFR-014
  - Files/areas: physical board; results to `MEASUREMENTS.md`
  - Work: continuity on all five SPI lines through their series resistors;
    GND common; **confirm the barrel-jack rail reaches U1's socket only and
    U2's 5 V socket pin is isolated**. Apply 5.00 V and measure the protected
    rail. Apply **reverse polarity deliberately** and confirm F1 trips with no
    damage and self-recovers. Short the keyboard port briefly and confirm F1
    trips and recovers. Measure F1's in-circuit resistance.
  - Validation: all isolation, polarity and overcurrent checks pass with no
    modules fitted (AC-3, AC-4, AC-5, AC-6).
  - Done when: every check passes and **every measured value is written down**,
    not just observed.

- [ ] 9. Populated bring-up and acceptance
  - ID: T-009
  - Requirement(s): FR-001, FR-004, FR-009, FR-010, FR-017, FR-018, FR-020,
    FR-021, FR-022, NFR-014
  - Files/areas: physical board + two S3-Zero modules running v1 firmware
  - Work: seat both modules; **reflash in situ using the modules' own
    BOOT/RESET buttons** with the board assembled (AC-2). Measure and record
    loaded keyboard VBUS with the highest-draw keyboard available — this is the
    on-board confirmation of the T-002 breadboard figure. Test **all** power-up
    orderings, especially KBD-first with TGT cold. Connect a powered USB-UART
    adapter to an **unpowered** module and confirm no damage; confirm the debug
    headers carry no supply voltage. Reproduce the v1 acceptance tests AC1–AC5:
    typing, Caps/Num LED backchannel, hot-plug recovery, watchdog.
  - Validation: AC-1, AC-2, AC-7, AC-8, AC-9, AC-13 all pass, with the VBUS
    figure recorded.
  - Done when: the bridge works on v0.2 hardware and the recorded VBUS
    measurement either confirms or corrects the T-002 prediction. **A
    discrepancy between breadboard and board is a finding to write up, not a
    rounding error to ignore.**

- [ ] 10. Reproduction check and spec close-out
  - ID: T-010
  - Requirement(s): NFR-012, NFR-013, NFR-014
  - Files/areas: `BUILD.md`, `README.md`, `design.md`, this file,
    `AGENTS.md`, `~/.pi/memory-md/kbdrelay/core/HARDWARE.md`
  - Work: verify a board can be built from the repo documentation alone
    (AC-14). Regenerate the as-built table from the final board file and confirm
    every documented figure matches. Fold the recorded measurements into
    `design.md` so the accepted risks are either closed or restated with
    evidence. Update `AGENTS.md` and the durable hardware notes. Tag the
    release.
  - Validation: no documented as-built figure differs from the board file; no
    acceptance criterion is left unrecorded.
  - Done when: the spec reads as a true account of what was built — the thing
    v0.1 failed at, requiring a retroactive reconstruction.

## Verification Checklist

- [x] Requirements IDs are referenced by tasks. All 20 FR and 14 NFR appear in
      at least one task.
- [x] Design testing strategy is represented by tasks. Its eight gates map to
      T-002 (breadboard), T-003 (ERC), T-004 (BOM), T-005 (DRC + ground),
      T-008 (bare board), T-009 (populated + system), T-010 (reproduction).
- [x] Each task has a clear validation command or manual check.
- [x] Rollback/migration tasks are included when applicable. **N/A by
      construction** — new hardware in a new directory; v0.1 is frozen at tag
      `v0.1-board` and no v0.1 file is modified. Firmware is unchanged, so both
      board revisions run identical binaries.

## Execution Notes

- Keep `Status: tasks-draft` until the user explicitly approves this task plan.
- After approval, change status to `tasks-approved` and run
  implementation-readiness validation before starting work.
- **T-002 gates T-005.** Layout must not begin before the breadboard
  measurement is recorded. T-003 and T-004 may proceed in parallel with T-002,
  since the net list does not depend on the measured value — only the choice of
  F1 does, and a substitution there is a value change, not a topology change.
- Record deviations from design in `design.md` **before** implementing them.
- Measurements are recorded when taken (NFR-014). An unrecorded measurement
  counts as not having happened — this is the v0.1 failure mode this spec is
  built to avoid.
- Where an automated attempt fails, record it as a limitation of that attempt,
  never as a proof of impossibility. Two such claims were made during v0.1 and
  both were later disproved by hand.
- The `make test` hook covers host firmware unit tests and is **not relevant to
  these tasks** — firmware is unchanged. PCB tasks are hardware-verified.

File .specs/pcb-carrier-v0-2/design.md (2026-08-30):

# PCB Carrier Board v0.2 Design

Spec: `pcb-carrier-v0-2`  
Status: design-approved  
Created: 2026-08-29  
Brainstorm: `./brainstorm.md`
Requirements: `./requirements.md`

## Summary

A two-layer, through-hole carrier PCB that sockets two Waveshare ESP32-S3-Zero
modules and joins them into the kbdrelay bridge. The board provides the five-wire
SPI interconnect with series protection, a common ground, a protected 5 V feed to
the KBD module only, and two debug UART headers. Three connectors reach the
outside world at board edges: each module's own USB-C, plus a 2.1 × 5.5 mm barrel
jack for power.

The single most consequential design decision is the **reverse-polarity
topology**, and it is settled by arithmetic rather than preference. FR-018 allows
a total of 0.60 V from the jack to the keyboard port at 500 mA. A series Schottky
(v0.1's answer) consumes roughly 0.40 V of that on its own, and the best
acceptable PPTC consumes another 0.29 V — **0.69 V, over budget before any copper
is drawn**. A shunt crowbar diode consumes **zero volts** in normal operation and
delivers the same protection, so v0.2 uses a shunt crowbar. This is the clearest
possible demonstration that v0.1's power path could not have met v0.2's
requirements, which is what a clean sheet is for.

One term in that budget has never been measured by anyone: the drop *inside* the
S3-Zero module, from its VDD pin to the VBUS pin of its USB-C connector. It could
plausibly be anywhere from a few millivolts of copper to a full Schottky drop if
the module carries a backfeed-blocking diode. Everything downstream of the
protection choice depends on it, so **D-004 makes measuring it a precondition for
layout**, not a bring-up surprise.

## Goals and Non-Goals

### Goals

- Meet the FR-018 voltage budget with measured evidence, not arithmetic alone
  (FR-018, D-004).
- Protect against reverse polarity at zero steady-state voltage cost (FR-013,
  FR-014).
- Produce a board manufacturable by PCBWay's standard 2-layer 1 oz service with
  zero DRC violations against their published rules (NFR-001, NFR-002).
- Make every non-module part orderable from one distributor by MPN (NFR-005),
  using stock KiCad footprints wherever one exists (NFR-006).
- Guarantee a single continuous ground region by construction and verify it
  (NFR-008).
- Keep documentation derivable from the board files rather than restated
  (NFR-013).

### Non-Goals

- Overvoltage protection. Deliberately excluded per EC-002.
- Any enclosure consideration beyond edge-mounted connectors (D-005).
- Firmware or pin-mapping changes (DC-001).
- Reuse of any v0.1 artifact (Overview, Out of Scope).

## Architecture

Three electrically distinct domains share one ground. The KBD domain is fed and
protected by this board; the TGT domain is powered entirely by the target machine
and this board deliberately supplies it nothing but ground and signals.

```mermaid
flowchart LR
  PSU["5V PSU<br/>2.1x5.5mm centre +"] --> J1["J1 barrel jack<br/>board edge"]
  J1 -->|"+5V_IN"| F1["F1 PPTC<br/>resettable overcurrent"]
  F1 -->|"+5V_PROT"| CROW["D1 shunt Schottky<br/>cathode to rail, anode to GND<br/>0V drop when correct"]
  CROW --> BULK["C1 470uF + C2 100nF<br/>inrush reservoir"]
  BULK -->|"+5V_KBD"| U1["U1 = KBD module<br/>ESP32-S3-Zero"]
  U1 -->|"internal VDD to VBUS<br/>UNMEASURED"| KBUSB["U1 USB-C<br/>board edge"]
  KBUSB --> KB["USB keyboard<br/>via A-to-C adapter"]

  U1 <-->|"SPI x5 through R1-R5<br/>GP4 GP5 GP6 GP7 GP8"| U2["U2 = TGT module<br/>ESP32-S3-Zero"]
  U1 --- GND(("common GND"))
  U2 --- GND

  U2 -->|"USB device"| TGUSB["U2 USB-C<br/>board edge"]
  TGUSB --> TGT["target machine<br/>supplies U2's only 5V"]

  U1 -->|"TX RX through R6 R7"| JD1["J2 debug UART KBD<br/>no supply pin"]
  U2 -->|"TX RX through R8 R9"| JD2["J3 debug UART TGT<br/>no supply pin"]

  X["U2 VDD: NOT CONNECTED<br/>keeps the 5V domains separate"] -.-> U2
```

## Power Path Design

### Topology

```
J1.tip (+5V_IN) ── F1 (PPTC) ──┬── D1 cathode        ── C1 ── C2 ──┬── U1.VDD
                               │   (D1 anode to GND)               │
J1.sleeve ──────────────────── GND ────────────────────────────────┘
```

`D1` is reverse-biased and electrically invisible during normal operation. Under
reverse polarity it conducts, `F1` heats and trips, and the fault collapses to a
trickle; correcting the supply restores normal operation with nothing replaced
(FR-013, FR-014). `F1` must sit **upstream** of `D1` — that ordering is what lets
it interrupt the fault. `F1` simultaneously serves as the keyboard overcurrent
protection (FR-015), because U1 is the only load on the rail, so one part does
both jobs.

### Voltage budget (FR-018)

Allowance is 0.60 V total, from 5.00 V at the jack to 4.40 V at the keyboard
port, at 500 mA (D-003).

| Term | Worst case @ 500 mA | Basis |
|---|---|---|
| Barrel jack contact | ~0.015 V | typical contact resistance |
| F1 PPTC | **0.290 V** | Bel 0ZRE0100FF1A, R₁max 0.58 Ω (post-trip worst case; 0.22 Ω initial gives 0.110 V fresh) |
| D1 shunt crowbar | **0.000 V** | reverse-biased in normal operation |
| Board copper | ~0.020 V | short, wide 1 oz traces |
| Module socket contacts | ~0.020 V | two contacts in the path |
| **Subtotal on the carrier** | **~0.345 V** | |
| **Remaining for U1 internal VDD→VBUS** | **~0.255 V** | **UNMEASURED — see D-004** |

Rejected alternative, for the record:

| Topology | Protection drop @ 500 mA | Verdict |
|---|---|---|
| Series 1N5817 + 0ZRE0100 | 0.40 + 0.29 = **0.69 V** | **Fails FR-018** before copper |
| Series SB540 + 0ZRE0100 | ~0.30 + 0.29 = **0.59 V** | Fails once copper and sockets are added |
| **Shunt crowbar + 0ZRE0100** | **0.29 V** | **Selected** |

### PPTC selection trade-off

The Littelfuse 60R090 used in v0.1 is electrically *better* than the Bel Fuse
alternatives, but requires the hand-built footprint v0.1 created because the
stock Bourns footprint staggers its pads for kinked leads.

| Part | Hold | R₁max | Drop @ 500 mA | Stock KiCad footprint |
|---|---|---|---|---|
| Littelfuse 60R090 | 0.90 A | 0.47 Ω | 0.235 V | ✗ (hand-built) |
| **Bel 0ZRE0100FF1A** | **1.00 A** | **0.58 Ω** | **0.290 V** | ✓ `Fuse_BelFuse_0ZRE0100FF_L18.7mm_W5.1mm` |
| Bel 0ZRE0075FF1A | 0.75 A | 0.84 Ω | 0.420 V | ✓ |

**Selected: Bel 0ZRE0100FF1A**, preferring NFR-006's stock footprint at a cost of
0.055 V. The 0ZRE0075 is rejected outright — 0.42 V leaves nothing for the module.
If the D-004 breadboard shows the module's internal drop is large, the fallback is
to switch to the 60R090 and reinstate the hand-built footprint, buying back
0.055 V. A 0.5 A-class PPTC is not considered: v0.1 established that it derates to
roughly 0.42 A at 40 °C and would nuisance-trip a legal 500 mA keyboard.

### Inrush

`C1` = 470 µF electrolytic, `C2` = 100 nF ceramic, both immediately upstream of
U1.VDD (FR-017). This is the validated fix for the keyboard-inrush brownout
observed on v1 hardware (DC-008) and is carried forward deliberately.

## Schematic Design

### Net list

| Net | Members |
|-----|---|
| `+5V_IN` | J1.tip, F1.1 |
| `+5V_PROT` | F1.2, D1.K, C1.+, C2.1, U1.VDD |
| `GND` | J1.sleeve, D1.A, C1.−, C2.2, U1.GND, U2.GND, J2.3, J3.3 |
| `SPI_SCK_K` / `SPI_SCK_T` | U1.GP4 → R1 → U2.GP4 |
| `SPI_MOSI_K` / `SPI_MOSI_T` | U1.GP5 → R2 → U2.GP5 |
| `SPI_MISO_K` / `SPI_MISO_T` | U1.GP6 → R3 → U2.GP6 |
| `SPI_CS_K` / `SPI_CS_T` | U1.GP7 → R4 → U2.GP7 |
| `SPI_DRDY_K` / `SPI_DRDY_T` | U1.GP8 → R5 → U2.GP8 |
| `UART_K_TX` / `UART_K_RX` | U1.TX → R6 → J2.1; U1.RX → R7 → J2.2 |
| `UART_T_TX` / `UART_T_RX` | U2.TX → R8 → J3.1; U2.RX → R9 → J3.2 |
| *(no net)* | **U2.VDD — explicitly no-connect (FR-012)**; U1/U2 3V3 and GPIO1,2,3,9,10,11,12,13 |

`U2.VDD` carries an explicit no-connect flag in the schematic so ERC records the
isolation as intentional rather than as an omission.

### Bill of materials

All through-hole (NFR-004). Modules are exempt from the sourcing rule (DC-007).

| Ref | Qty | Value / MPN | Footprint | Purpose / requirement |
|-----|-----|---|---|---|
| U1, U2 | 2 | Waveshare ESP32-S3-Zero | `kbdrelay:ESP32-S3-Zero-Socketed` (project lib) | KBD and TGT (FR-001) |
| — | 4 | 1×9 female header 2.54 mm | part of module footprint | sockets (FR-002) |
| — | 4 | 1×9 male header 2.54 mm | — | soldered into module pad rows |
| J1 | 1 | CUI **PJ-102AH** (2.1 × 5.5 mm) | `Connector_BarrelJack:BarrelJack_CUI_PJ-102AH_Horizontal` | 5 V input (FR-011) |
| F1 | 1 | Bel Fuse **0ZRE0100FF1A** | `Fuse:Fuse_BelFuse_0ZRE0100FF_L18.7mm_W5.1mm` | overcurrent + crowbar interrupt (FR-015) |
| D1 | 1 | **1N5822** (3 A / 40 V Schottky) | `Diode_THT:D_DO-201AD_P12.70mm_Horizontal` | shunt crowbar (FR-013, FR-014) |
| C1 | 1 | 470 µF / 16 V electrolytic | `Capacitor_THT:CP_Radial_D10.0mm_P5.00mm` | inrush reservoir (FR-017) |
| C2 | 1 | 100 nF ceramic disc | `Capacitor_THT:C_Disc_D5.0mm_W2.5mm_P5.00mm` | HF decoupling |
| R1–R5 | 5 | 2.2 kΩ 1/4 W | `Resistor_THT:R_Axial_DIN0207_L6.3mm_D2.5mm_P10.16mm_Horizontal` | SPI series (FR-008) |
| R6–R9 | 4 | 1 kΩ 1/4 W | same | UART series (FR-022) |
| J2, J3 | 2 | 1×3 pin header 2.54 mm | `Connector_PinHeader_2.54mm:PinHeader_1x03_P2.54mm_Vertical` | debug UART, **no supply pin** (FR-020, FR-021) |

**Twelve distinct line items, all THT, all single-distributor.** No LED (D-001),
no mounting hardware (FR-005 withdrawn), no soft-reset header.

`D1` is a 3 A part rather than 1 A because it must survive the fault current until
F1 trips, and its forward drop sets the clamp voltage the modules see under
reverse polarity — lower is better. The DO-201AD 12.70 mm footprint accepts an
even beefier SB540/SB560 with no board change.

### Library plan

| Asset | Source | Rationale |
|---|---|---|
| Barrel jack, PPTC, resistors, caps, headers, diode | **stock KiCad libraries** | NFR-006 |
| ESP32-S3-Zero symbol + footprint | project library, vendored | no stock equivalent exists |

v0.1's hand-built `PPTC_Littelfuse_60R_P5.08mm` footprint is **not carried
forward** — the Bel Fuse part's stock footprint replaces it. The module footprint
remains the only hand-built asset, and its 1.0 mm drill / 2.0 mm pad gives a
0.50 mm annular ring against PCBWay's 0.25 mm minimum (DC-005), comfortably
compliant now that holes are plated.

## Layout Design

### Stack-up and rules

Two layers, 1 oz. **F.Cu carries signals; B.Cu is a solid, uninterrupted ground
pour.** This is the structural fix for v0.1's split-pour defect (F-6, NFR-008):
with all signal routing on the opposite layer, nothing can wall off a ground
region in the first place. Vias are available and unremarkable, so the entire
crossing/jumper problem that dominated v0.1 simply does not arise.

| Parameter | Value | PCBWay minimum (DC-005) |
|---|---|---|
| Signal trace | 0.30 mm | 0.127 mm |
| Power trace (`+5V_*`) | 1.00 mm | 0.127 mm |
| Clearance | 0.25 mm | 0.127 mm |
| Via | 0.6 mm pad / 0.3 mm drill | 0.5 mm / 0.3 mm |
| Track to edge | 0.40 mm | 0.30 mm |

Every figure sits at least 2× PCBWay's floor. There is no reason to crowd their
limits: this design has enormous area headroom, and margin costs nothing.

### Placement

- **U1 (KBD) at the left edge, U2 (TGT) at the right edge**, USB-C connectors
  overhanging their respective board edges via the footprint's 1.5 mm notch
  (FR-003, DC-003).
- **J1 barrel jack on the front long edge, near U1** — keeps the high-current
  path short and puts power next to the module it feeds (FR-011).
- Power chain F1 → D1 → C1/C2 clustered between J1 and U1.VDD.
- R1–R5 in a single column mid-board between the two modules.
- J2 near U1, J3 near U2, both reachable from above.
- **No board-mounted component may obstruct either module's BOOT/RESET buttons**
  (FR-004) — this is a placement rule, checked visually against the module
  outline.

**Outline: minimise, bounded by hand-assembly access (NFR-003, NFR-016).** The
100 × 100 mm figure is a cost bracket, not a target, and is expected to be
non-binding. v0.1 needed 88 × 55 mm largely because single-sided routing forced
parts apart; two layers plus the deleted LED and mounting holes remove that
pressure, so **≈ 70 × 45 mm is a plausible projection and not a commitment**.
The outline is an output of layout (D-005).

The binding constraint on shrinking is NFR-016, and the parts that set it are
the physically large ones: C1 (10 mm diameter can), F1 (18.7 mm body), D1 on a
12.70 mm pitch, and J1's barrel-jack body. Layout must keep an iron path to
every joint with neighbours already fitted — in practice this means the power
cluster, not the resistor field, sets the minimum area. Verified on the
assembled board per AC-15, because CAD clearance and iron access are not the
same check.

### Ground continuity

B.Cu is a single pour with no signal routing to fragment it. Verification is
mechanical, not visual: a script loads the board through `pcbnew`, fills zones,
and asserts the GND zone resolves to exactly **one** connected region with zero
unconnected items — the check v0.1 lacked when it shipped a silently split pour.

## Error Handling

Hardware equivalents — how each fault presents and recovers.

| Fault | Behaviour | Recovery | Ref |
|---|---|---|-----|
| Reverse-polarity supply | D1 conducts, F1 trips, rail collapses | Correct supply; F1 self-resets | FR-013, FR-014 |
| Keyboard short or overcurrent | F1 trips | Remove fault; F1 self-resets | FR-015, EC-003 |
| Wrong-voltage supply (12/19 V) | **Modules destroyed** | None — deliberately unprotected | EC-002 |
| High-inrush keyboard | C1 supplies surge; no brownout | Automatic | FR-017 |
| Peer module unpowered | Series R limits backfeed; no latch-up | Automatic | FR-008, FR-009 |
| Powered debug adapter on unpowered module | Series R limits injected current | Automatic | FR-022, EC-006 |
| Sagging supply | VBUS falls; keyboard may misbehave | Use a supply that holds 5.00 V | EC-007 |
| Keyboard over 500 mA | F1 trips rather than sagging indefinitely | Use a lower-draw keyboard | EC-008 |

## Testing Strategy

Ordered by when each gate runs. **The breadboard gate precedes layout** — that
ordering is the whole point of D-004.

1. **Breadboard power-path validation (precondition for layout, D-004).**
   Build J1 → F1 → D1 → C1/C2 → module on a breadboard. At exactly 5.00 V input
   and 500 mA load, measure and record: voltage at the jack, at U1.VDD, and at
   the keyboard VBUS. This yields the unmeasured module internal drop and
   confirms or refutes the FR-018 budget **before** any copper is committed.
   Also verify reverse polarity trips F1 and self-recovers. Records per NFR-014.
2. **Schematic gate.** `kicad-cli sch erc` → zero violations (NFR-007). U2.VDD
   confirmed no-connect.
3. **BOM gate.** Every non-module line item confirmed in stock at one
   distributor with an MPN (NFR-005, AC-12).
4. **Layout gate.** `kicad-cli pcb drc` against the vendored PCBWay `.kicad_dru`
   → zero violations (NFR-002). Ground-continuity script → exactly one region
   (NFR-008, AC-11). Both are commands, not opinions.
5. **Bare-board bring-up.** Continuity on all five SPI lines through their
   series resistors; GND common; **U2.VDD isolated from the rail**; deliberate
   reverse-polarity application; keyboard-port short. (AC-3, AC-4, AC-5, AC-6)
6. **Populated bring-up.** Seat modules, reflash in situ via module buttons
   (AC-2), measure and **record** loaded keyboard VBUS ≥ 4.40 V (AC-7), all
   power-up orderings (AC-8), powered debug adapter on an unpowered module
   (AC-9).
7. **System acceptance.** v1 firmware reproduces v1 AC1–AC5: typing, Caps/Num
   LED backchannel, hot-plug, watchdog (AC-13).
8. **Reproduction gate.** A board is built following only the repo docs, with no
   undocumented steps (AC-14).

## Rollout and Migration

No migration exists — this is new hardware, and v0.1 is frozen at tag
`v0.1-board`. v0.2 lives in a new KiCad project directory so no v0.1 file is
touched or overwritten. Firmware is unchanged, so a v0.1 board and a v0.2 board
run identical binaries.

Fab outputs go to exactly one canonical directory, versioned in the filename
(NFR-010, NFR-011) — the v0.1 failure where the board of record was named
`test2` while a stale, DRC-failing layout held the canonical name.

## Requirements Traceability

| Requirement | Design Decision | Validation |
|---|---|---|
| FR-001 | Two S3-Zero module positions, U1/U2 | AC-1 |
| FR-002 | 4× 1×9 female socket strips | AC-1 |
| FR-003 | Modules at left/right edges, USB-C over the 1.5 mm notch | AC-1 |
| FR-004 | Placement rule: nothing obstructs BOOT/RESET | AC-2 |
| FR-006 | R1–R5 between matching GP4–GP8 pins | AC-3 |
| FR-007 | U1.GND, U2.GND on the B.Cu pour | AC-3 |
| FR-008 | 2.2 kΩ series per SPI line | AC-3 |
| FR-009 | Series R limits backfeed into an unpowered peer | AC-3, bring-up |
| FR-010 | No sequencing element in the design | AC-8 |
| FR-011 | J1 = CUI PJ-102AH at the front edge | AC-1 |
| FR-012 | U2.VDD explicit no-connect | AC-4 |
| FR-013 | D1 shunt crowbar + F1 upstream | AC-5 |
| FR-014 | PPTC self-resets; no fusible parts | AC-5 |
| FR-015 | F1 = 0ZRE0100FF1A, 1.0 A hold | AC-6 |
| FR-016 | Silkscreen `5V ⏜ centre +` at J1 | visual |
| FR-017 | C1 470 µF + C2 100 nF at U1.VDD | AC-7 |
| FR-018 | Budget table; crowbar chosen to fit it | **breadboard (D-004)** then AC-7 |
| FR-020 | J2, J3 1×3 headers | AC-9 |
| FR-021 | No supply net on J2/J3 | AC-9 |
| FR-022 | 1 kΩ series per UART line | AC-9 |
| NFR-001 | 2-layer 1 oz, all rules ≥2× PCBWay floor | AC-10 |
| NFR-002 | Vendored `.kicad_dru`, DRC gate | AC-10 |
| NFR-003 | Minimise outline; 100 × 100 mm cost bracket non-binding | measure outline |
| NFR-016 | Power-cluster spacing sets minimum area; iron access preserved | AC-15 |
| NFR-004 | Every part THT | BOM review |
| NFR-005 | 12 line items, one distributor, MPNs listed | AC-12 |
| NFR-006 | Stock footprints for all but the module | BOM review |
| NFR-007 | ERC gate | AC-10 |
| NFR-008 | Signals on F.Cu only; solid B.Cu pour; scripted region check | AC-11 |
| NFR-010 | Single canonical `fab/` directory | file review |
| NFR-011 | Version in filenames and silkscreen | file review |
| NFR-012 | BUILD.md written for a stranger | AC-14 |
| NFR-013 | As-built table generated from the board file | doc review |
| NFR-014 | Measurements recorded at breadboard and bring-up | AC-7 |

## Risks and Trade-offs

- **The module's internal VDD→VBUS drop is unknown and could break the budget.**
  It has roughly 0.255 V of headroom. If the S3-Zero carries a backfeed-blocking
  Schottky on its 5 V path, that alone could consume all of it. *Mitigation:*
  D-004 measures it before layout. *Fallbacks, in order:* switch F1 to the
  Littelfuse 60R090 (+0.055 V, costs a hand-built footprint); accept a
  documented supply above 5.00 V (contradicts D-003, so a requirements change,
  not a design tweak); bypass the module's 5 V path entirely by feeding keyboard
  VBUS from the carrier — which is not possible, since USB is only available at
  the module connector (DC-002). **The third fallback not existing is why this
  measurement gates layout.**
- **The crowbar relies on F1 tripping rather than blocking current outright.**
  A series diode fails safe by construction; a crowbar fails safe by dynamics.
  With a current-limited bench supply F1 may never trip, leaving D1 forward-
  biased and dissipating — nothing downstream is powered and nothing is damaged,
  but it is a "stuck" state rather than a clean cutoff. *Accepted:* the outcome
  is safe in every case; only the mechanism is less absolute.
- **Overvoltage remains unprotected** (EC-002). Deliberate. Silkscreen and
  documentation are the only mitigations.
- **Bel Fuse PPTC costs 0.055 V versus the Littelfuse part** purely to satisfy
  NFR-006. If the budget turns out tight, this is the first thing to trade back.
- **Compactness and assembly ease pull against each other.** NFR-003 wants the
  smallest board; NFR-016 wants iron access with neighbours fitted. The large
  THT parts (C1, F1, D1, J1) mean the power cluster dominates the minimum area,
  so shrinking the signal side buys little. *Mitigation:* NFR-016 explicitly
  wins, and AC-15 checks it on real hardware rather than in CAD. The 70 × 45 mm
  figure is a projection, not a commitment.
- **No impossibility claims appear in this document.** v0.1 produced two, both
  later disproved by hand. Where this design says something cannot be done —
  board-mounted USB, board-mounted BOOT/RESET — it is because the module does
  not expose the pins (DC-002), which is a fact about the part, not a failed
  search.

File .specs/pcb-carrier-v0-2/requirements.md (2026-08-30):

# PCB Carrier Board v0.2 Requirements

Spec: `pcb-carrier-v0-2`  
Status: requirements-approved  
Created: 2026-08-29  
Brainstorm: `./brainstorm.md`

> **ID namespace:** v0.2 requirement IDs are freshly numbered and do **not**
> correspond to v0.1's `FR-001..FR-032` / `NFR-001..NFR-008`. When referring to a
> v0.1 requirement, always qualify it as `v0.1 FR-nnn`. v1 *system* requirements
> from the root `spec.md` are cited as `v1 FR5.1` etc. and remain binding.

## Overview

Clean-sheet redesign of the kbdrelay carrier PCB for professional fabrication at
PCBWay (2-layer, 1 oz) and reproduction by third-party builders. New schematic
and layout; the Waveshare ESP32-S3-Zero modules, their pin mapping, and the v1
firmware are unchanged. Barrel-jack 5 V input with re-derived protection,
continuous ground plane, THT-only discretes sourceable from Digikey-class
retailers, free board outline driving a 3D-printed enclosure with a removable
lid. Retires the entire home-etch toolchain and its constraints.

## Scope

### In Scope

- A new schematic, drawn from scratch. The v0.1 netlist is not carried over.
- The KBD 5 V power path and its protection, re-derived: reverse polarity,
  overcurrent, and inrush.
- A barrel-jack 5 V input, replacing v0.1's 2-pin header.
- A 2-layer PCBWay-manufacturable layout with a continuous ground plane.
- PCBWay design rules vendored into the repo as a project-local DRC gate.
- A board outline free of external mechanical constraint, which the 3D-printed
  enclosure is then designed to fit.
- Retained per-module debug UART headers, reachable by removing the lid.
- THT-only discrete components with verified, orderable manufacturer part
  numbers.
- Build, assembly, and bring-up documentation written for a third party.
- A versioned fabrication package (Gerbers, drill, BOM) in the repo.

### Out of Scope

- **Firmware changes.** The S3-Zero pin mapping is fixed and this board adapts
  to it, not the reverse.
- **Module substitution.** The Waveshare ESP32-S3-Zero stays.
- **Board-mounted USB connectors** of any kind. Physically impossible with this
  module — see DC-002.
- **Board-mounted BOOT/RESET buttons.** Also physically impossible — see DC-002.
- **Revisiting the v1 FR5 5 V-isolation architecture.** It holds unchanged.
- **Surface-mount components.**
- **Detailed enclosure CAD.** The enclosure follows the finished board and is
  not specified here beyond the constraints it imposes on the board.
- **The entire home-etch toolchain**, explicitly retired: LCD photoresist
  exposure artwork, `bridge_risk.py`, `audit_gaps.py`, the wire-jumper budget,
  the `BOTTOM` copper label, and single-sided routing.
- **Selling or shipping assembled units.**
- **Overvoltage protection.** Deliberately excluded; see FR-016 and EC-002.

## User Stories

- As a **retrocomputing hobbyist**, I want to clone the repo, order the board
  from PCBWay, and buy every component from a mainstream electronics retailer,
  so that I can build a working kbdrelay without sourcing detective work.
- As a **first-time builder**, I want assembly and bring-up documentation that
  assumes no prior knowledge of this project, so that I can tell whether my
  board works before I connect it to a machine I care about.
- As a **builder who owns a 3D printer**, I want the board's connectors on its
  edges and its outline documented, so that a printed case fits it and the
  external connections line up.
- As **someone with a drawer full of wall adapters**, I want a wrong supply to
  fail safe rather than destroy the boards, so that a careless mistake costs
  nothing.

## Functional Requirements

### Module interface

- **FR-001**: THE carrier SHALL mechanically and electrically host exactly two
  Waveshare ESP32-S3-Zero modules, designated U1 (KBD) and U2 (TGT).
- **FR-002**: THE carrier SHALL mount both modules in **sockets**, such that
  either module can be removed and refitted without desoldering.
- **FR-003**: THE carrier SHALL position both modules so that each module's
  USB-C connector sits at a board edge, clear of the board outline.
- **FR-004**: THE carrier SHALL leave both modules' onboard BOOT and RESET
  buttons physically operable while both modules are seated, unobstructed by
  any board-mounted component.

*(FR-005 and FR-023 were withdrawn during requirements review. FR-005 required
mounting provision — a reflex carried over from v0.1, which needed corner holes
because it was a bare board; an enclosure designed to fit this board can capture
it without fixings, and mounting is deferred until a case actually exists.
FR-023 required the modules' status LEDs to face the lid, which is automatic:
modules socket onto the top face, so their LEDs already point up. A requirement
that cannot be violated is not a requirement.)*

### Bridge interconnect

- **FR-006**: THE carrier SHALL connect the five SPI signals between U1 and U2
  using the firmware's fixed pin mapping: SCK on GP4, MOSI on GP5, MISO on GP6,
  CS on GP7, and DATA_READY on GP8.
- **FR-007**: THE carrier SHALL connect U1 GND and U2 GND to a common ground
  (v1 FR5.4).
- **FR-008**: THE carrier SHALL place a series resistance in each of the five
  SPI signal paths, sized to limit backfeed current into an unpowered peer
  module (v1 FR5.4).
- **FR-009**: WHEN one module is powered and the other is not, THE carrier SHALL
  NOT allow either module to be damaged or latched up (v1 FR5.4).
- **FR-010**: WHEN the two modules are powered in any order, THE bridge SHALL
  reach normal operation without manual intervention.

### Power domains and protection

- **FR-011**: THE carrier SHALL accept 5 V input through a single **2.1 × 5.5 mm
  centre-positive** DC barrel jack, which SHALL be the board's only external
  power input and SHALL sit at a board edge.
- **FR-012**: THE carrier SHALL route the barrel-jack supply to U1 (KBD) only,
  and SHALL leave U2's 5 V pin unconnected, so that the two 5 V domains are
  never joined (v1 FR5.1, v1 FR5.3).
- **FR-013**: IF a reverse-polarity supply is connected to the barrel jack, THE
  carrier SHALL prevent damage to either module, to the carrier, and to an
  attached keyboard.
- **FR-014**: WHEN a reverse-polarity supply is corrected, THE carrier SHALL
  return to normal operation without replacing any component.
- **FR-015**: THE carrier SHALL provide resettable overcurrent protection on the
  keyboard 5 V rail, such that a sustained overcurrent or a short at the
  keyboard port is interrupted and recovers without component replacement.
- **FR-016**: THE carrier SHALL carry silkscreen marking at the barrel jack
  stating the required supply voltage and polarity (`5V ⏜ centre +`).
- **FR-017**: THE carrier SHALL provide bulk capacitance on the KBD 5 V rail
  sufficient that a high-inrush USB keyboard enumerates on first plug-in without
  browning out the module.
- **FR-018**: WHILE supplying a keyboard drawing up to 500 mA, THE carrier SHALL
  maintain keyboard VBUS at or above **4.40 V**, measured at the keyboard port,
  from a **5.00 V** input at the barrel jack. *(5.00 V is the design point, not
  a recommended supply voltage: it is the honest worst case for a builder using
  a generic adapter. Any higher input is headroom, never a requirement — see
  D-003.)*

*(FR-019 was withdrawn during requirements review: it capped protection losses
at 0.35 V, which double-specified the same physical quantity FR-018 already
bounds. Allocating that budget across protection, copper and socket contact
resistance is design work, not a requirement. IDs are never reused.)*

### Debug and diagnostics

- **FR-020**: THE carrier SHALL provide one debug UART header per module,
  exposing that module's TX, RX, and GND.
- **FR-021**: THE debug UART headers SHALL NOT expose any supply voltage.
- **FR-022**: THE carrier SHALL place a series resistance in each debug UART
  signal path, sized to survive a powered USB-UART adapter being connected to an
  unpowered module.

## Non-Functional Requirements

### Manufacturability

- **NFR-001**: THE board SHALL be manufacturable by PCBWay's standard 2-layer,
  1 oz copper service.
- **NFR-002**: THE repo SHALL contain PCBWay's design rules as a project-local
  `.kicad_dru`, and the board SHALL report **zero DRC violations** against them
  via `kicad-cli pcb drc`.
- **NFR-003**: THE board outline SHALL be no larger than 100 × 100 mm, and
  SHALL be the smallest outline that satisfies NFR-016. *(The 100 × 100 mm
  figure is PCBWay's standard prototype pricing bracket, not a fabrication
  limit; it is expected to be non-binding in practice. Compactness is the
  active goal, bounded by assembly ergonomics rather than by area.)*
- **NFR-016**: THE board SHALL remain hand-assemblable, such that: no component
  body overhangs another component's pads or obstructs access to them; every
  through-hole joint is reachable with a conventional soldering iron with the
  adjacent parts already fitted; and polarised parts are oriented consistently
  where practical. *(Compactness under NFR-003 is subordinate to this. v0.1
  produced the counterexample — a mounting hole so close to C1's body that the
  build notes had to specify a low-profile screw head.)*
- **NFR-004**: ALL board-mounted components other than the two modules SHALL be
  through-hole. No surface-mount parts.
- **NFR-005**: EVERY board-mounted component other than the two modules SHALL be
  orderable from a single mainstream electronics distributor, identified in the
  BOM by manufacturer part number. The ESP32-S3-Zero modules are exempt from
  this requirement.
- **NFR-006**: WHERE a stock KiCad library footprint exists for a part, THE
  design SHALL use it in preference to a hand-built footprint.
- **NFR-007**: THE schematic SHALL report zero ERC violations via
  `kicad-cli sch erc`.

### Electrical integrity

- **NFR-008**: THE ground net SHALL form a single electrically continuous
  region, verified as such rather than assumed. *(Addresses v0.1 retro finding
  F-6, where the ground pour silently split into two islands.)*
*(NFR-009 was withdrawn during requirements review: "no copper gap below the
PCBWay minimum" is precisely what NFR-002's DRC run against the vendored PCBWay
rules checks. v0.1 retro finding F-7 is covered by NFR-002.)*

### Reproducibility and documentation

- **NFR-010**: THE repo SHALL contain a fabrication package sufficient to order
  the board without opening KiCad, stored in exactly one canonical location.
- **NFR-011**: THE board files, fabrication outputs, and documentation SHALL
  carry an unambiguous version identifier, such that no artifact can be confused
  with a different revision. *(Addresses v0.1 retro finding F-3.)*
- **NFR-012**: THE build documentation SHALL be sufficient for a builder with no
  prior knowledge of this project to fabricate, assemble, and verify a board.
- **NFR-013**: ANY as-built parameter stated in documentation SHALL be derivable
  from the board files by a repeatable command, not restated by hand.
  *(Addresses v0.1 retro finding F-2, where prose drifted from copper in five
  places simultaneously.)*
- **NFR-014**: BRING-UP measurements SHALL be recorded in the spec at the time
  they are taken. *(Addresses v0.1 retro finding F-4, where verification
  happened but was never written down, and F-8, where a voltage margin was
  accepted without ever being measured.)*

*(NFR-015 was withdrawn during requirements review: "never record a failed
search as a proof of impossibility" is a working convention, not a property of
the board, and it already lives in `AGENTS.md` where it will actually be read.
v0.1 retro finding F-1 is addressed there.)*

## Acceptance Criteria

- [ ] **AC-1** — Two modules seat in sockets, are removable, and both USB-C
      connectors sit at board edges clear of the outline, as does the barrel
      jack. *(FR-001, FR-002, FR-003, FR-011)*
- [ ] **AC-2** — A firmware reflash is performed with both modules seated on the
      assembled board, using the modules' own BOOT/RESET buttons. *(FR-004)*
- [ ] **AC-3** — Continuity confirms all five SPI lines on the GP4–GP8 mapping,
      each through its series resistance, and a common ground. *(FR-006, FR-007,
      FR-008)*
- [ ] **AC-4** — Isolation confirms the barrel-jack rail reaches U1 only and
      U2's 5 V pin is unconnected. *(FR-012)*
- [ ] **AC-5** — A reverse-polarity supply is applied deliberately; no damage
      results, and normal operation resumes once corrected, with no parts
      replaced. *(FR-013, FR-014)*
- [ ] **AC-6** — A short at the keyboard port trips protection and recovers with
      no parts replaced. *(FR-015)*
- [ ] **AC-7** — The highest-draw available keyboard enumerates on first plug-in,
      and **keyboard VBUS is measured and recorded** at or above 4.40 V.
      *(FR-017, FR-018, NFR-014)*
- [ ] **AC-8** — The bridge reaches normal operation from every power-up
      ordering, including KBD-first with TGT cold. *(FR-010)*
- [ ] **AC-9** — A powered USB-UART adapter is connected to an unpowered module
      without damage, and the debug headers are confirmed to carry no supply
      voltage. *(FR-020, FR-021, FR-022)*
- [ ] **AC-10** — `kicad-cli sch erc` and `kicad-cli pcb drc` both report zero
      violations, the latter against the vendored PCBWay rules. *(NFR-002,
      NFR-007)*
- [ ] **AC-11** — The ground net is verified to be a single continuous region by
      a repeatable check. *(NFR-008)*
- [ ] **AC-12** — The BOM lists a manufacturer part number for every part, and
      every non-module part is confirmed orderable from one distributor.
      *(NFR-005)*
- [ ] **AC-15** — Every through-hole joint is reachable with a conventional iron
      with adjacent parts fitted, and no component body overhangs another's
      pads. Confirmed on the assembled board, not only in CAD. *(NFR-016)*
- [ ] **AC-13** — The v1 firmware reproduces the v1 acceptance tests AC1–AC5 on
      this board: typing, the Caps/Num LED backchannel, hot-plug recovery, and
      watchdog behavior.
- [ ] **AC-14** — A board is fabricated and assembled following only the repo's
      documentation, with no undocumented steps required.

## Edge Cases

*(EC-001, EC-003, EC-004 and EC-005 were withdrawn during requirements review:
each restated a functional requirement and pointed at its acceptance criterion
without adding information. Reverse polarity is FR-013/FR-014, keyboard
overcurrent is FR-015, inrush is FR-017, and the powered/unpowered peer case is
FR-008/FR-009. The edge cases below are the ones that are **not** already fully
stated by a requirement.)*

- **EC-002 — Wrong-voltage supply.** A 2.1 × 5.5 mm barrel plug is a mechanical
  standard only, so any 9 V, 12 V or 19 V adapter physically fits. **This is
  deliberately unprotected**: no through-hole-only network survives a
  high-current 19 V supply, so the mitigation is FR-016's silkscreen marking
  plus the documented supply specification. Accepted risk, recorded here so it
  is never mistaken for an oversight.
- **EC-006 — Powered debug adapter on an unpowered module.** A USB-UART adapter
  can back-power a module through its TX pin. Covered by FR-022; verified by
  AC-9.
- **EC-007 — Undervoltage supply.** A nominally 5 V adapter sagging under load,
  or a long thin cable, erodes the FR-018 margin. The design must state the
  input voltage its budget assumes.
- **EC-008 — Keyboard exceeding 500 mA.** RGB keyboards at full brightness can
  exceed the FR-018 figure. Best-effort per v1 FR5.2; protection should trip
  rather than sag indefinitely.

## Dependencies and Constraints

- **DC-001 — Firmware is fixed.** SPI is SCK/GP4, MOSI/GP5, MISO/GP6, CS/GP7,
  DATA_READY/GP8; the console is UART0. The board adapts to firmware.
- **DC-002 — The S3-Zero exposes only 18 pins**: VDD, GND, 3V3, GPIO1–13, RX,
  TX. It does **not** break out GPIO19/20 (native USB D±), nor EN/RESET, nor
  GPIO0. Consequences, both binding: USB exists only at each module's own USB-C
  jack, so board-mounted USB receptacles are impossible; and BOOT/RESET exist
  only as the modules' own buttons, so download mode requires physical access to
  them.
- **DC-003 — Module USB-C jacks are on the modules, not the PCB.** Both modules
  must therefore sit at board edges, and enclosure cutouts follow the layout
  rather than constraining it.
- **DC-004 — Two MCUs are forced by silicon.** One ESP32-S3 has a single USB
  PHY, so host and device duty cannot share a chip. This is not a design choice
  and is not open for review.
- **DC-005 — PCBWay 2-layer 1 oz limits**, from the supplied rules file:
  0.127 mm track width and clearance, 0.25 mm minimum annular ring, 0.3 mm
  track-to-edge, 0.5 mm hole-to-hole across different nets, 0.5 mm minimum
  non-plated hole, vias 0.3 mm hole / 0.5 mm diameter. The file targets KiCad 7
  but has been verified to parse and enforce on KiCad 10.0.5.
- **DC-006 — The enclosure is downstream and imposes nothing.** See D-005. The
  board is constrained only by NFR-003's size limit and by keeping the three
  external connectors on board edges.
- **DC-007 — Sourcing rule scope.** NFR-005 governs electronic components. The
  ESP32-S3-Zero modules are explicitly exempt and are expected to be bought
  from general online retailers.
- **DC-008 — Bench-earned facts carried forward deliberately.** Although the
  schematic is a clean sheet, four findings were paid for in brownouts and
  latch-ups rather than chosen for etching convenience, and are retained as
  requirements above: bulk capacitance for inrush (FR-017), series resistance on
  SPI for backfeed (FR-008), no supply pin on debug headers (FR-021), and TGT's
  5 V left unconnected (FR-012).
*(DC-009 was withdrawn during requirements review: "v0.1 is a reference, not a
baseline" is already stated by the Overview and the Out of Scope list.)*

## Amendments

- **A-001 (2026-08-29, post-approval)** — **NFR-003 reframed and NFR-016 added.**
  The original NFR-003 was a bare 100 × 100 mm ceiling, which expressed no
  preference about how large the board actually ends up. Compactness is now the
  stated goal, with the ceiling retained only as a cost bracket, and NFR-016
  added as its explicit counterweight so that "compact" cannot be pursued into
  an unassemblable board. Requires re-approval of the requirements gate.

## Decisions

Resolved during requirements review. Recorded so the reasoning survives.

- **D-001 — No carrier-mounted status LED.** The modules' own firmware-driven
  RGB LEDs are the status indication. A carrier LED would duplicate them while
  telling the builder strictly less than a meter reading — the same reasoning
  that withdrew v0.1's power-good LED. No board-side obligation follows: the
  modules socket component-side up, so their LEDs already face away from the
  board.
- **D-005 — The enclosure is not a design input.** The board's only concession
  to a future case is that the three external connectors sit at board edges
  (FR-003, FR-011). Outline, mounting, cutouts and any light path are deferred
  until a case is actually built, and will adapt to the board rather than
  constrain it.
- **D-002 — Barrel jack is 2.1 × 5.5 mm, centre-positive.** 5.5 mm specifies
  only the outer diameter; the 2.1 mm centre pin must be stated because 5.5 mm
  jacks also exist with a 2.5 mm pin, and the two mismate badly — a 2.1 mm plug
  makes intermittent contact in a 2.5 mm jack, and a 2.5 mm plug will not enter
  a 2.1 mm jack at all. 2.1 × 5.5 mm is the common hobbyist standard.
- **D-003 — The power budget is designed against exactly 5.00 V.** Verification
  is by bench supply set to 5.00 V, which makes FR-018 directly measurable
  rather than aspirational. This deliberately rejects v0.1's approach of
  recommending a 5.1–5.25 V supply to buy margin: that pushes the design's
  weakness onto the builder's choice of adapter, and a stranger following the
  build will reach for a generic 5 V brick. Any input above 5.00 V is headroom,
  never a requirement.
- **D-004 — The FR-018 power budget is validated by breadboarding v0.2's
  candidate protection topology, before layout.** Not by measuring v0.1, whose
  hardware is not to hand, and not by arithmetic alone. This makes the
  design-gate protection choice an empirical result rather than an assertion,
  which is the specific failure v0.1 made when it accepted a VBUS margin nobody
  ever measured (retro finding F-8). The breadboard measurement is taken at
  5.00 V input per D-003, recorded per NFR-014, and is a **precondition for
  layout**, not a bring-up step.

## Open Questions

*None. All questions raised during brainstorm and requirements review are
resolved and recorded under Decisions above.*

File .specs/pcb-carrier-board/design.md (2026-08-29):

# Pcb Carrier Board Design

Spec: `pcb-carrier-board`
Status: design-approved  
Closed: 2026-08-27 — superseded for future work by the v0.2 effort. This spec is
the **v0.1 record**; do not amend it further. See `../pcb-carrier-v0-2/` and the
v0.1 retrospective at `../../hardware/pcb-carrier/RETRO-v0.1.md`.
Created: 2026-08-18
Brainstorm: `./brainstorm.md`
Requirements: `./requirements.md`

## Summary

A single-sided, through-hole "carrier" PCB that mechanically and electrically
joins two socketed Waveshare ESP32-S3-Zero modules (KBD + TGT) into the kbdrelay
bridge, replacing the breadboard harness. USB stays on each module's USB-C
(keyboard → KBD USB-C via adapter; TGT USB-C → target). The carrier provides:
the SPI interconnect (with series resistors), KBD's protected 5 V power path
(series-Schottky reverse polarity → bulk cap → polyfuse), strict isolation of the TGT 5 V
domain, a power-good LED, per-module UART headers (with series resistors), and a
reserved (unpopulated) soft-reset header. Firmware is unchanged from v1.

Design tool: KiCad (single copper layer routed on the bottom; components +
wire-jumper links on top). All discretes through-hole.

## Goals and Non-Goals

### Goals

- Reproduce verified v1 behavior with socketed modules, no hand-wiring
  (FR-001..FR-005).
- Enforce the FR5 power rules and back-power protection by construction
  (FR-010..FR-013, FR-020..FR-026).
- Be etchable at home on a single copper layer with THT parts (NFR-001,
  NFR-006), while keeping the keyboard's VBUS within USB limits.

### Non-Goals

- Fab-house/production optimization, SMD, multi-layer, integrated USB
  connectors, enclosure — deferred to a future "product" spec.
- Any firmware change (soft-reset feature is only *reserved* in hardware).

## Architecture

```mermaid
flowchart LR
  KB[USB keyboard] -->|USB-A→C adapter| KBDUSB[KBD USB-C]
  subgraph CARRIER[Single-sided THT carrier PCB]
    PWR[2-pin 5V header] --> RP[Schottky reverse-polarity]
    RP --> BULK[470µF + 0.1µF]
    BULK --> PF[polyfuse ~0.5A]
    PF --> KBD5V[KBD module 5V pin]
    SPI[5x 2.2kΩ series R on SCK/MOSI/MISO/CS/DATA_READY]
    RST[reserved RST header - GP9 both, unpopulated]
    UART1[KBD UART hdr +1kΩ]
    UART2[TGT UART hdr +1kΩ]
    LED[power-good LED]
  end
  KBDUSB --- KBDMOD[KBD S3-Zero module]
  KBD5V --- KBDMOD
  KBDMOD <-->|GP4-8| SPI
  SPI <-->|GP4-8| TGTMOD[TGT S3-Zero module]
  TGTMOD --- TGTUSB[TGT USB-C]
  TGTUSB -->|USB-C→A| TARGET[Target machine]
  TARGET -.VBUS powers TGT.-> TGTMOD
  GND[(common ground)] --- CARRIER
```

- The carrier carries **power + SPI + GND + debug**, never USB data.
- **KBD** is powered by the carrier (from the 5 V header) and sources the
  keyboard's VBUS out its own USB-C. **TGT** is powered only by the target
  through its USB-C; the carrier does **not** connect to the TGT 5V pin.
- Both module USB-C ports face board edges for cabling.

## Schematic design (nets, values, candidate parts)

### Power path (KBD) — FR-010..FR-013, FR-020..FR-022

```
J_PWR(+5V) ──▶|── D_rev(1N5817) ──┬── C_bulk(470µF) ──┬── F_poly(PPTC ~0.5A) ── KBD.5V
                                   │   C_dec(0.1µF)    │
J_PWR(GND) ────────────────────────┴── common GND ─────┴───────────────────────── KBD.GND
```

- **Reverse polarity (series Schottky) — REVISED:** a plain **series Schottky
  diode**, anode → +5 V input, cathode → protected rail. Reversed input: the
  diode blocks → protected. This supersedes the earlier P-FET ideal-diode
  design, which is dropped for **sourcing reasons**: logic-level POWER P-FETs in
  THT (TO-220, Vgs(th) ≤2 V, Rds(on) ≤100 mΩ @ −4.5 V) are effectively
  unobtainable at hobby quantities, while Schottkys are on hand.
  Part: **1N5817** (1 A, 20 V, DO-41 axial); **1N5819** (40 V) is a drop-in.
  Symbol: `Device:D_Schottky`; footprint: `Diode_THT:D_DO-41_SOD81_P10.16mm_Horizontal`.
- **Voltage-headroom consequence (the one real cost):** at the expected ~0.3 A
  (KBD module + keyboard) the 1N5817 drops ≈**0.30–0.35 V** and the PPTC adds
  **0.06–0.14 V** (60R090), so a 5.00 V input lands the keyboard at
  ≈**4.5–4.6 V** — above the USB 4.40 V floor, but the margin is finite where
  the P-FET's was not. (With the originally-specified 0.5 A PPTC the worst case
  was 4.30 V, i.e. **out of spec** — that is what drove the 0.9 A revision.)
  Mitigations, in order of preference:
  1. Feed J_PWR from a **5.1–5.25 V** supply (a USB-C PD/5 V brick measures
     high anyway); this restores full margin.
  2. If a marginal keyboard appears, fit a **SB540/SB560** (5 A, DO-201AD,
     Vf ≈0.2–0.25 V at 0.3 A) — a larger axial part on the same 2-pad
     footprint pitch.
  3. Keep the rail trace short/fat (1.0 mm) so copper IR is negligible.
  **Layout note:** provide the diode pads with enough pitch/pad size to also
  accept a DO-201AD body, so the SB5x0 upgrade needs no board respin.
- **Verify at bring-up:** measure the protected rail and the keyboard VBUS with
  the highest-draw keyboard attached; **VBUS must read ≥4.40 V**.
- **Bulk cap:** 470 µF (≥10 V) radial electrolytic + 0.1 µF ceramic, placed at
  the KBD 5V pin — the validated fix for keyboard inrush brownout.
- **Polyfuse (REVISED — 0.5 A → 0.9 A hold):** radial THT PPTC in series to the
  KBD 5V pin, **Littelfuse 60R090** — hold **0.90 A**, trip **1.80 A**, 60 V,
  Rₘᵢₙ 0.20 Ω / R₁ₘₐₓ **0.47 Ω**, body 11.2 × 3.1 mm, leads on 5.08 mm centres.
  Supersedes the original ≈0.5 A / ≈1 A specification for two measured reasons:
  1. **Nuisance-trip headroom.** A USB device may legally draw **500 mA**; plus
     the KBD module (~60–80 mA) the legitimate load reaches **~0.58 A**. PPTC
     hold current derates with ambient (**83 % at 40 °C**), so a 0.5 A part
     holds only ~0.42 A in a warm enclosure and would trip on a legal keyboard.
     0.90 A derates to ~0.75 A — a **29 % margin** over 0.58 A.
  2. **Voltage headroom.** PPTC resistance scales inversely with hold rating.
     Worst-case drop at 0.3 A falls from **0.35 V (60R050, R₁ₘₐₓ 1.17 Ω)** to
     **0.14 V (60R090)** — 0.21 V handed back to keyboard VBUS, which is what
     makes the series-Schottky choice comfortable rather than marginal.
  Not taken any higher: at 60R110's 2.2 A trip a typical 5 V brick current-limits
  first, which would move protection from the fuse to the supply.
  Still satisfies FR-022 (passes ≥250 mA; clamps a short at 1.8 A).
- **TGT power:** the TGT module's 5V pin is **left unconnected** on the carrier.
  Only GND + SPI reach TGT → FR5.1/FR5.3 by construction.

### SPI interconnect — FR-002, FR-023

- Straight pin-to-pin between modules on the locked map, each line through a
  **2.2 kΩ series resistor** placed near the driving module:

  | Signal | KBD pin | TGT pin |
  |--------|---------|---------|
  | SCK    | GP4     | GP4     |
  | MOSI   | GP5     | GP5     |
  | MISO   | GP6     | GP6     |
  | CS     | GP7     | GP7     |
  | DATA_READY | GP8 | GP8     |

- Series R limits inter-module backfeed/latch-up and cures the power-up-order
  pre-charge; at ≤1 MHz the RC with short traces is negligible.

### Reset & flashing access — FR-030

- **The shared GP9 soft-reset node is REMOVED** (was: GP9 on both modules via
  1 kΩ each to an unpopulated 2-pin `RST_BTN` header). Dropped for two reasons:
  1. **It never satisfied FR-030.** FR-030 exists to support the *download-mode
     flashing sequence*, which requires the hardware BOOT+RESET sequence. A GP9
     line calling `esp_restart()` in firmware cannot enter download mode, and
     per the v1 bench notes a software/line reset over native USB does not even
     reliably restart the app.
  2. **It cost real routing space.** `RST_BTN` is a net spanning *both* modules,
     i.e. a full board-width run on a single-copper-layer board — a likely
     forced jumper, in exchange for a feature nobody would use on a prototype.
- **FR-030 is satisfied instead by the modules' own onboard BOOT and RESET
  buttons.** The S3-Zeros sit in sockets on the top face, so their buttons stay
  physically reachable. This makes it a **placement constraint, not a circuit**:
  → *Layout SHALL leave both modules' BOOT and RESET buttons operable with the
  boards seated — no tall neighbouring parts blocking finger/tool access.*
- **GP9 is left unconnected** on both modules (no-connect flags). Deliberately
  not broken out to pads either — on a single-sided board the routing cost is
  real and the feature is unused. Revisit only if a **two-layer** revision
  happens, where a shared reset node is nearly free to route.
- Consequence accepted: there is no one-button "reset both modules". Power-cycle
  J3 (KBD) or the target link (TGT), or press each module's own RESET.

### Debug UART — FR-026, FR-031

- Per module: **3-pin header (TX, RX, GND)**; **1 kΩ series R** on TX and RX so
  a plugged-in USB-UART adapter cannot back-power/sustain the module (the bench
  lesson). VCC intentionally absent from the header.

### Indication — FR-032

- One **power-good LED + ~1 kΩ resistor** across the protected 5 V rail.
- Per-role status remains on each module's onboard WS2812 (GPIO21).

## Connectors & pinouts (external interfaces)

- **J_PWR** — 2-pin (5V, GND) THT header; external 5 V source (user's choice).
- **Module sockets** — female 0.1" headers matching the S3-Zero (≈1×9 + 1×12
  per module); modules removable.
- **J_UART_KBD / J_UART_TGT** — 3-pin (TX/RX/GND) each.
- *(J_RST removed — see "Reset & flashing access".)*
- **USB** — not on the carrier; each module's USB-C, edge-accessible.

## Error handling → Fault & protection behavior

- **Reversed 5 V input:** series Schottky blocks; no current, no damage (FR-020).
- **Keyboard inrush:** bulk cap holds the rail; no brownout (FR-021).
- **Keyboard/cable short:** polyfuse trips, protecting source/board; resets when
  cleared (FR-022).
- **One module unpowered / any power-up order:** 2.2 kΩ series R limits backfeed
  so neither chip latches and an unpowered TGT still cold-starts cleanly when
  the target powers it (FR-023..FR-025).
- **Debug adapter attached:** 1 kΩ series on UART + no VCC pin prevents
  back-powering (FR-026).

## Security and Privacy → Target-hardware safety

- Not applicable in the software sense. The relevant safety property is
  **never sourcing power into the (possibly vintage) target**: guaranteed by
  leaving the TGT 5V pin unconnected and by the series-R'd SPI (only GND + weak,
  resistor-limited signals reach the TGT side). FR5.3.

## Testing Strategy

- **Bare-board checks:** visual/continuity — 5 V and TGT-5V domains isolated;
  GND common; SPI pin-to-pin; Schottky orientation (band = cathode = load side);
  polyfuse in series.
- **Power-on (no modules):** apply 5 V, verify protected rail ≈ input − ~0.3 V,
  power-good LED on; apply reversed 5 V, verify no rail.
- **Headroom check (loaded):** with the highest-draw keyboard running, measure
  keyboard VBUS — **must be ≥4.40 V**; if not, raise the supply to ~5.2 V or
  fit the SB5x0 alternate.
- **Populated bring-up:** install modules + v1 firmware; reproduce AC1–AC5
  (typing, Caps/Num LED, hot-plug, watchdog) — these are the acceptance tests.
- **Fault tests:** high-inrush keyboard enumerates first try; brief keyboard-VBUS
  short trips the polyfuse; verify all power-up orders (esp. KBD-first).
- No automated tests (hardware); `bridge_proto` host tests remain green as the
  firmware is unchanged.

## Rollout and Migration → Fabrication & assembly plan

- **Single copper layer** (bottom) routed in KiCad; components + **wire-jumper
  links** on top; **no plated vias**. Target **≤ ~8 jumpers**, each listed in
  build notes (NFR-001, NFR-006). **Achieved: zero jumpers** — see the layout
  amendment below.
- **Home-fab profile (starting targets, finalized in layout):** signal traces
  ~0.5 mm, power traces ~1.0 mm, clearance ~0.5 mm, drills ~0.9 mm with generous
  ~2 mm pads.
- **As-routed profile (scripted router, superseded):** signal 0.7 mm, power/GND
  1.5 mm, clearance 0.4 mm, module + PPTC drills 1.0 mm / 2.0 mm pads, all other
  parts library default. ⚠ **This is not what shipped** — see amendment 6.

### Layout amendment (2026-08-21) — as-built placement

Approved deviations recorded here per the "record deviations before
implementing" rule:

1. **Board is 88 × 55 mm, not 120 × 55 mm.** The first placement left ~30 mm of
   dead space between the middle cluster and the modules. Width came out of
   whitespace only; the arrangement from the user's sketch (modules at the short
   edges, USB-C exiting each end, discretes in the middle) is unchanged.
2. **The five SPI series resistors are one column, not two banks.** R1–R5 sit at
   x = 45 mm on a 5 mm row pitch (y = 34/29/24/19/14). The two-bank arrangement
   existed only to span the wider board and cost ~20 mm of width.
3. **TGT UART cluster moved with U2** (J2 at x = 60, R8/R9 rotated 180° so their
   module-side pad faces U2).
4. **The board is placed centred on the A4 drawing sheet** (origin 104.5, 77.5)
   rather than at the sheet origin, so the title block frames the board.
5. **4× M3 mounting holes** at the board corners, 3.5 mm in. The bottom-left
   hole's courtyard clips C1's body outline — mechanically fine, but use a
   low-profile screw/washer there.
6. **GND is a B.Cu pour with solid (not thermal-relief) pad connections**, plus
   three GND-only keep-clear channels. Without those channels the pour cannot
   reach C1.2, C2.2 and U2.2 once the +5 V and SPI runs wall them off — a
   silent, real fault that a pour alone hides.

**The "≥1 jumper is topologically forced" claim in tasks.md T-004 is wrong.**
It applied an annulus argument that ignores routing *around* a module and
*under* a module body between its two pad rows. The board routes with **zero
crossings on one layer**, so neither parked escape hatch (flipping U2 to the
back layer, or reversing TGT's SPI pin assignment in firmware) is needed, and
the design gate does not need reopening.
- **Outputs:** KiCad project, a 1:1 bottom-copper print for toner-transfer/home
  etch, and standard Gerbers for a PCB house.
- **BOM (all THT):** 1N5817 Schottky (SB540 alternate), 60R090 PPTC, 470 µF,
  0.1 µF, 5× 2.2 k (SPI), 4× 1 k (UART), LED + 1 k, J_PWR (1×2),
  2× UART (1×3), module socket headers. Board outline + 4× M3 holes.
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

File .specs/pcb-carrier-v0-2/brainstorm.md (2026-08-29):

# PCB Carrier Board v0.2 Brainstorm

Spec: `pcb-carrier-v0-2`  
Status: brainstorm-complete  
Created: 2026-08-29

## User Intent

## Brainstorm Summary

- **User intent:** Redesign the kbdrelay carrier board as v0.2 from a clean sheet — new schematic, nothing carried over from the v0.1 netlist or layout — targeting professional fabrication at PCBWay and reproduction by other builders, while keeping the hardware-proven Waveshare ESP32-S3-Zero modules and the v1 firmware untouched.

- **Target users/stakeholders:** Other hobbyist / retrocomputing builders who clone the repo, order boards from PCBWay, buy the BOM from online electronics retailers, and assemble a working bridge. The author is the first builder and maintainer.

- **Problem and desired outcome:** v0.1 proved the concept but is fundamentally a home-etch artifact — single-sided, hand-routed, 0.605 mm minimum copper gap, a split GND pour, hand-built footprints, a 2-pin power header, and no enclosure story. It is realistically reproducible only by its author. v0.2 should be a professionally fabbed 2-layer board living in a small 3D-printed box with three external connections (two module USB-C, one barrel jack), a sourceable BOM, and documentation a stranger can follow to a working unit.

- **In scope:**
  - New schematic drawn from scratch; the v0.1 netlist is not carried over
  - KBD 5 V protection re-derived (reverse polarity, overcurrent, inrush)
  - Barrel-jack 5 V input replacing v0.1's 2-pin header
  - 2-layer PCBWay-manufacturable layout with a continuous ground plane and vias
  - PCBWay `.kicad_dru` vendored into the repo as a project-local DRC gate
  - Free board outline; the 3D-printed enclosure is designed to fit the board afterwards
  - BOOT/RESET access via a removable lid (the modules' own buttons are the only option)
  - Internal debug UART headers retained
  - Onboard status LED(s) permitted
  - THT-only discrete components with verified, in-stock Digikey-class MPNs
  - Third-party build / assembly / bring-up documentation
  - A versioned fab package (Gerbers, drill, BOM)

- **Out of scope:**
  - Firmware changes; the S3-Zero pin mapping (SPI GP4–GP8, DATA_READY GP8, UART0 console) is fixed
  - Module substitution — the S3-Zero stays
  - Board-mounted USB connectors of any kind (physically impossible: see constraints)
  - Revisiting the FR5 5 V-isolation architecture (it holds unchanged)
  - Surface-mount parts
  - Detailed enclosure CAD (follows the board; may be a separate effort)
  - Home-etch support and its entire toolchain — LCD photoresist exposure artwork, `bridge_risk.py`, `audit_gaps.py`, the jumper budget, the `BOTTOM` copper label — all explicitly retired
  - Selling or shipping assembled units

- **Constraints/risks:**
  - **The S3-Zero exposes only 18 pins** — VDD, GND, 3V3, GPIO1–13, RX, TX. GPIO19/20 (native USB D±) are **not** broken out, so USB exists only at each module's own USB-C jack; a board-mounted USB-A receptacle for the keyboard is impossible without changing modules. EN/RESET and GPIO0 are likewise not exposed, so **board-mounted BOOT/RESET buttons are impossible** and download mode requires physical access to the modules' own buttons — hence the removable lid.
  - **Module USB-C jacks sit on the modules, not the PCB**, so both modules must sit at board edges using the footprint's 1.5 mm USB-C overhang notch, and the enclosure cutouts follow whatever the layout produces.
  - **PCBWay 2-layer 1 oz limits** (from the supplied `.kicad_dru`): 0.127 mm track width and clearance, 0.25 mm minimum annular ring, 0.3 mm track-to-edge, 0.5 mm hole-to-hole across different nets, 0.5 mm minimum non-plated hole, vias 0.3 mm hole / 0.5 mm diameter. The file is written for KiCad 7 but was verified to parse **and enforce** on KiCad 10.0.5 (canary rule test).
  - **Barrel jack has two independent failure modes.** Reverse polarity (centre-negative supply) is protectable cheaply. **Overvoltage is not** — a 2.1 × 5.5 mm plug is a mechanical standard only, so any 9/12/19 V brick fits and would destroy both modules; no THT-only protection network survives a high-current 19 V supply. Decision: protect reverse polarity, and mitigate overvoltage with silkscreen marking plus a documented PSU spec rather than parts.
  - **VBUS margin is unverified.** v0.1's loaded keyboard VBUS was never measured (retro finding F-8). Hardware is not to hand, but breadboarding is available, so the design gate can validate the power path empirically. Carried as an explicit open risk.
  - The two-MCU architecture is forced by silicon (one USB PHY per ESP32-S3), not a design choice.
  - PCBWay's minimum order quantity is a non-issue at these prices and is not a requirement.
  - The Waveshare S3-Zero is not a Digikey line item; it is **explicitly exempt** from the sourcing rule, which governs electronic components rather than dev modules.
  - The vendored S3-Zero symbol/footprint originates from a GitHub repo with no LICENSE file. Assessed by the user as not a concern; not tracked as a risk.
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

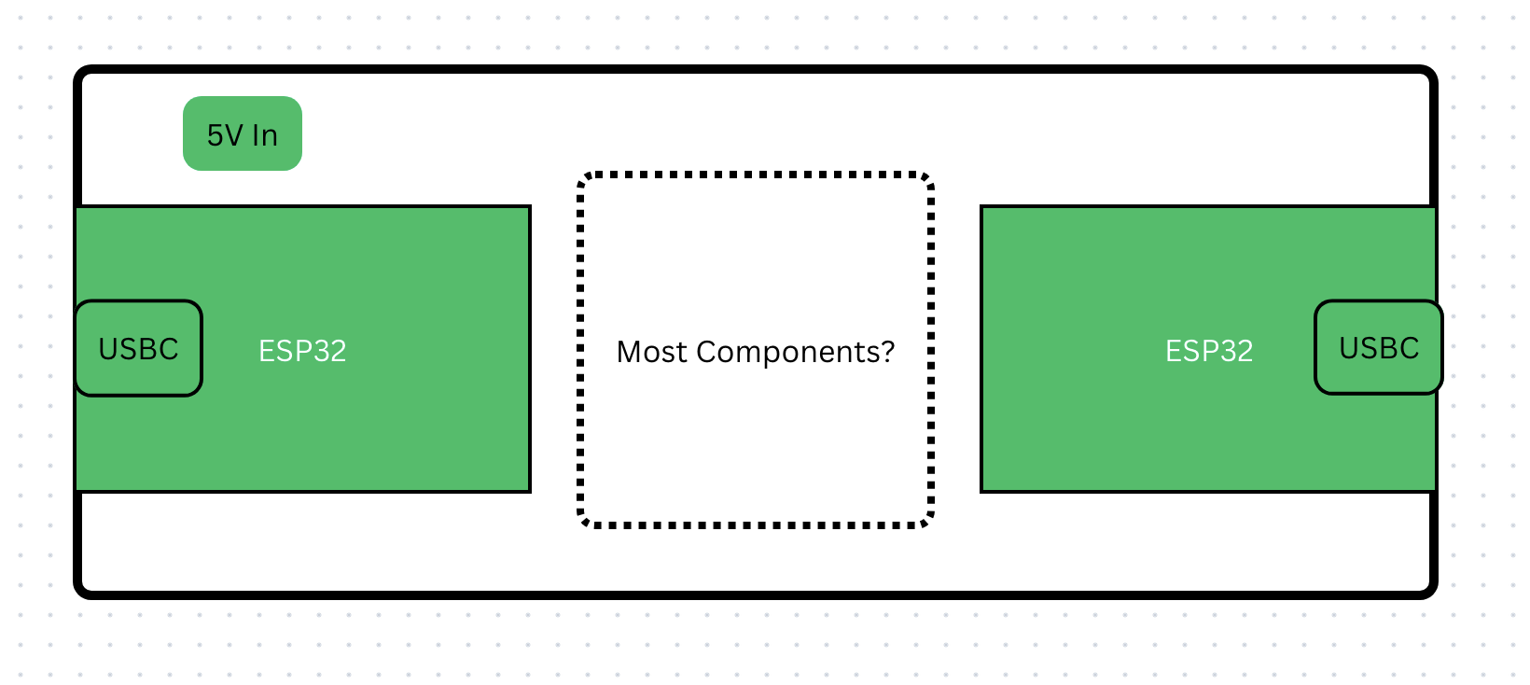
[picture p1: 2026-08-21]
hardware/v0.1_board_design.png

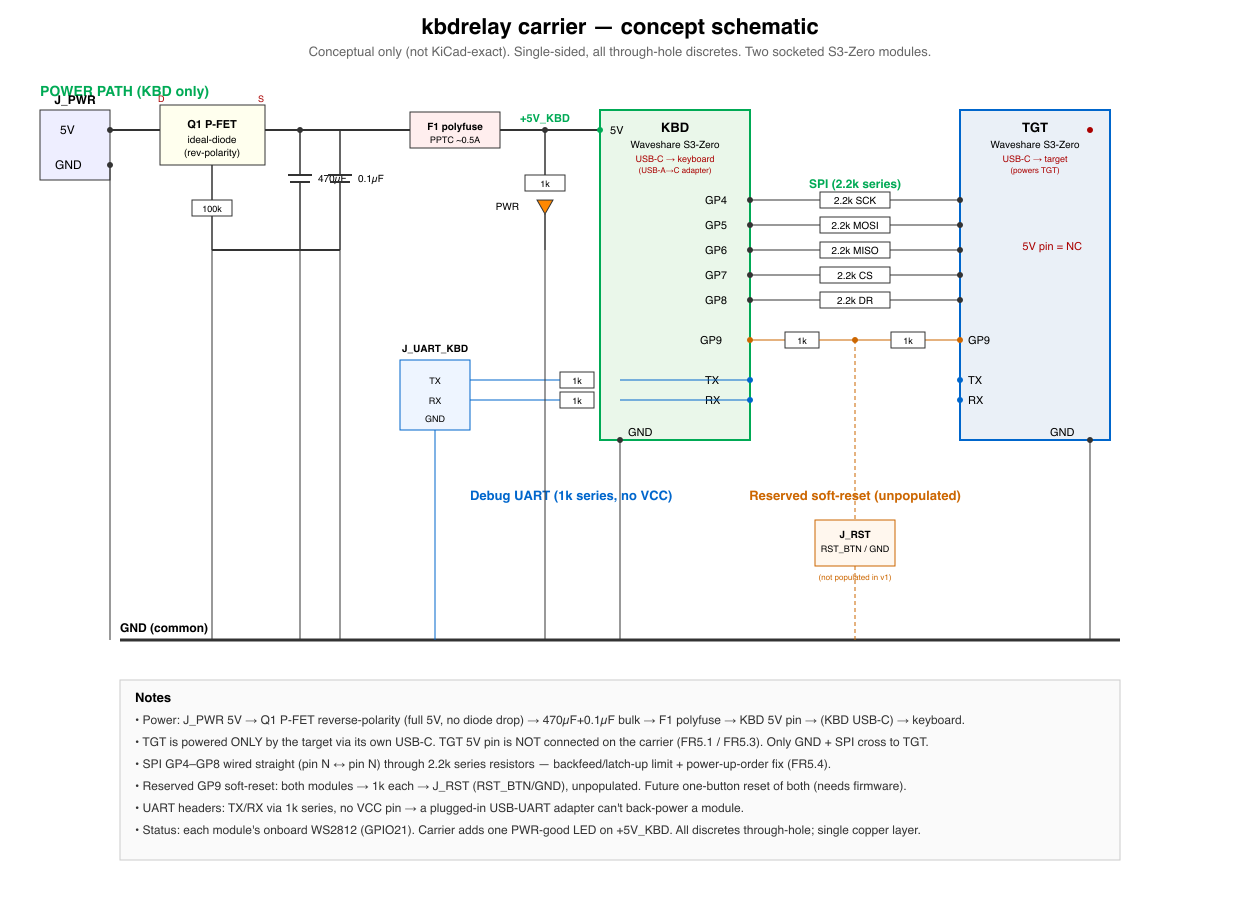
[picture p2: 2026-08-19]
hardware/pcb-carrier/schematic-concept.png

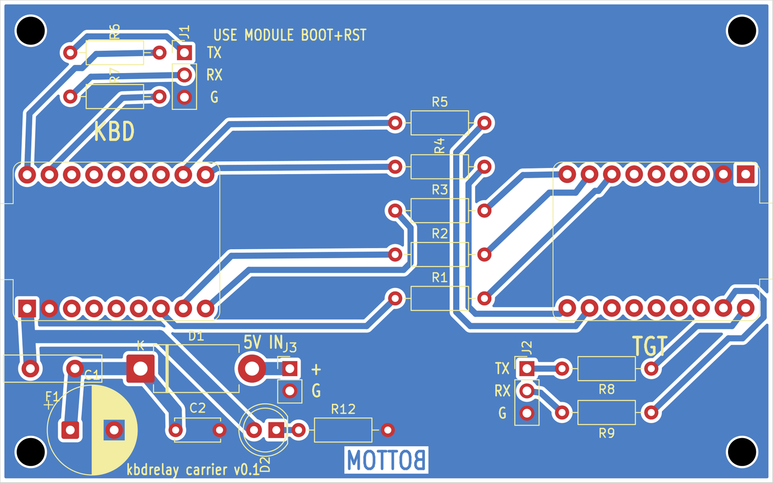
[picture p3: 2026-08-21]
hardware/pcb-carrier/preview/board.png

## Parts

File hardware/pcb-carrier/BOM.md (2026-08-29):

# kbdrelay carrier board — BOM

Source of truth: `kbdrelay-carrier/kbdrelay-carrier.kicad_sch` (ERC clean, 0 errors).
Board of record: `kbdrelay-carrier/kbdrelay-carrier-v0.1.kicad_pcb` (22 footprints).
All discretes are **through-hole (THT)**. Quantities are per board.

## Active / modules

| Ref | Qty | Value | Footprint | Notes |
|-----|-----|---|---|---|
| U1, U2 | 2 | Waveshare ESP32-S3-Zero | `kbdrelay:ESP32-S3-Zero` (project library) | U1 = KBD (keyboard side), U2 = TGT (target side). Socketed, not soldered. 2×9 THT pads, 2.54 mm pitch, 15.24 mm rows. |
| D1 | 1 | **1N5817** (1 A / 20 V Schottky) | `Diode_THT:D_DO-201AD_P12.70mm_Horizontal` | Reverse-polarity protection. 1N5819 (40 V) is a drop-in. Footprint is intentionally the larger DO-201AD/12.70 mm so an **SB540/SB560** lower-Vf part fits with no board respin. **Band (cathode) faces the load.** |

## Passives

| Ref | Qty | Value | Footprint | Purpose |
|-----|-----|---|---|---|
| C1 | 1 | 470 µF / 16 V electrolytic | `Capacitor_THT:CP_Radial_D10.0mm_P5.00mm` | Bulk cap — the validated fix for keyboard inrush brownout (FR-021). **Polarised: stripe = negative = GND.** |
| C2 | 1 | 100 nF ceramic disc | `Capacitor_THT:C_Disc_D5.0mm_W2.5mm_P5.00mm` | HF decoupling alongside C1. |
| F1 | 1 | **Littelfuse 60R090** PPTC (0.90 A hold / 1.80 A trip, 60 V) | `kbdrelay:PPTC_Littelfuse_60R_P5.08mm` (project library) | Resettable fuse on keyboard VBUS (FR-022). Rₘᵢₙ 0.20 Ω / R₁ₘₐₓ 0.47 Ω. Straight in-line leads, 5.08 mm pitch, 0.51 mm lead dia, body 11.2 × 3.1 mm. **Not** the 0.5 A part — see "why 0.9 A" below. |
| R1–R5 | 5 | 2.2 kΩ | `Resistor_THT:R_Axial_DIN0207_..._P10.16mm_Horizontal` | SPI series resistors — one per line (SCK/MOSI/MISO/CS/DATA_READY), FR-023. |
| R6–R9 | 4 | 1 kΩ | same as above | UART TX/RX series, 2 per module (FR-026). |

*(D2 + R12 — the power-good LED — were removed by design amendment: FR-032 was
withdrawn. Bring-up uses a meter reading of the protected rail, which it already
required, and an LED only reports "something is live". Neither part is on the
shipped v0.1 board.)*

*(R10/R11 and J4 — the shared GP9 soft-reset — were removed by design amendment.
FR-030 is met by the modules' own onboard BOOT/RESET buttons, which the layout
must leave accessible. GP9 is unconnected on both modules.)*

## Connectors

| Ref | Qty | Value | Footprint | Notes |
|-----|-----|---|---|---|
| J3 | 1 | 5V_IN (1×2) | `Connector_PinHeader_2.54mm:PinHeader_1x02_P2.54mm_Vertical` | Pin 1 = +5 V, pin 2 = GND. **KBD's only 5 V source.** |
| J1, J2 | 2 | UART_KBD / UART_TGT (1×3) | `..._PinHeader_1x03_P2.54mm_Vertical` | Pin1 = module TX, pin2 = module RX, pin3 = GND. **No VCC pin — deliberate** (FR-026). |
| — | 4 | **1×9** female headers, 2.54 mm | (part of the module footprint) | Two per module so the S3-Zeros are removable. Not a schematic symbol. Rows are 15.24 mm (0.6") apart. |
| H1–H4 | 4 | M3 mounting holes (3.2 mm, non-plated) | `MountingHole:MountingHole_3.2mm_M3` | Board corners, 3.5 mm in. Not a schematic symbol. H3 (bottom-left) sits close to C1's body — use a low-profile screw/washer. |

## Purchasing table (PCBWay assembly BOM)

**Machine-readable copy: [`kbdrelay-carrier-v0.1-BOM.csv`](kbdrelay-carrier-v0.1-BOM.csv)** — that
file is the one to upload. PCBWay accepts `.csv`/`.xls`/`.xlsx` only; markdown is
for humans. The CSV carries the full **turn-key** column set (Line#, Qty per P/N,
Reference Designator, Part Number, Part Description, Package, Type, Manufacturers
Name, Manufacturers Part Number, Distributors Part Number) per
<https://www.pcbway.com/assembly-file-requirements.html>, so it also satisfies the
shorter consigned/kitted set.

✅ **Every Digi-Key SKU below was resolved against the live Product Information V4
API on 2026-08-27** and is recorded with its package type, MOQ and stock at time
of lookup. All ten purchasable lines are **Active, MOQ 1, and in stock**.

⚠ **Three MPNs in the first draft were wrong.** The API caught all three; they were
plausible-looking guesses that would each have cost a re-order:

| Ref | Draft MPN | Problem | Corrected to |
|-----|---|---|---|
| C1 | `UVR1C471MPD` | Real part, but **8.00 mm dia / 3.50 mm lead spacing** — does not fit the `D10.0mm_P5.00mm` footprint | `EEU-FC1C471` (Panasonic FC, **10.00 mm dia / 5.00 mm LS**, 12.5 mm H) |
| C1 | `UVR1C471MED` | **Does not exist.** Invented by guessing at Nichicon's size-code scheme | — as above |
| C2 | `K104K15X7RF5TL2` | Real part, but **2.50 mm lead spacing** — footprint wants 5.00 mm | `K104K15X7RF53H5` (same Vishay K-series, **5.00 mm LS**) |
| R6–R9 | `CFR-25JB-52-1K0` | **Does not exist.** Yageo's 1 k suffix is `-1K`, not `-1K0` | `CFR-25JB-52-1K` |

The C1/C2 errors are the interesting ones: both draft parts were *real, orderable
parts with the right electrical spec and the wrong mechanical footprint*. A BOM
checked only on capacitance and voltage would have passed them.

**Centroid file: not applicable.** PCBWay only wants pick-and-place data for
surface-mount parts, and this board has none. Send Gerbers + BOM + the assembly
drawing; state "100% through-hole, no SMT" on the order.

**Line 1 (the modules) and line 11 (their pin strips) must be consigned** —
Waveshare S3-Zeros aren't a distributor stock item, and line 11 solders to the
*module*, not the carrier. Line 12 is hardware: do not assemble.

Quantities are per board. Every board-mounted item is **through-hole**; there
are no surface-mount parts. Part numbers marked *(rep.)* are representative
jellybean MPNs — any equivalent from a reputable maker is fine. Part numbers in
**bold** are design-critical: substitute only per the notes in this file.

| Line# | Qty per P/N | Reference Designator | Part Number | Part Description | Package | Type |
|---:|---:|---|---|---|---|---|
| Line# | Qty | Ref | Manufacturer | MPN | **Digi-Key SKU** | Pkg | Stock @ lookup |
|------:|----:|-----|--------------|-----|------------------|-----|---------------:|
| 1 | 2 | U1, U2 | Waveshare | ESP32-S3-Zero | *not stocked — buy direct* | — | — |
| 2 | 1 | D1 | Taiwan Semiconductor | **1N5817** | `1801-1N5817CT-ND` | Cut Tape | 3 080 |
| 3 | 1 | C1 | Panasonic Industry | EEU-FC1C471 | `P10248-ND` | Bulk | 15 960 |
| 4 | 1 | C2 | Vishay | K104K15X7RF53H5 | `BC3323-ND` | Bulk | 38 769 |
| 5 | 1 | F1 | Littelfuse | **60R090XU** | `F1923-ND` | Bulk | 1 048 |
| 6 | 5 | R1–R5 | YAGEO | CFR-25JB-52-2K2 | `2.2KQBK-ND` | Bulk | 69 020 |
| 7 | 4 | R6–R9 | YAGEO | CFR-25JB-52-1K | `1.0KQBK-ND` | Bulk | 241 553 |
| 8 | 1 | J3 | Sullins | PREC002SAAN-RC | `35-PREC002SAAN-RC-ND` | Bulk | 3 341 |
| 9 | 2 | J1, J2 | Sullins | PREC003SAAN-RC | `35-PREC003SAAN-RC-ND` | Bulk | 605 |
| 10 | 4 | U1/U2 sockets | Sullins | PPTC091LFBN-RC | `S7007-ND` | Tray | 4 548 |
| 11 | 4 | U1/U2 pins | Sullins | PREC009SAAN-RC | `35-PREC009SAAN-RC-ND` | Bulk | 853 |
| 12 | 4 | H1–H4 | — | M3×8 pan head + nut | *hardware, not assembled* | — | — |

Every line above is **MOQ 1** and **status Active**. D1 and C2/C1 notes:

- **D1** resolves to Taiwan Semiconductor's `1N5817` in DO-204AL/DO-41, the only
  exact-MPN part Digi-Key stocks under that number. It ships **Cut Tape**; the
  Tape & Reel variant (`1801-1N5817TR-ND`) is MOQ 5 000 and out of stock — do not
  order that one by mistake.
- **C1** `EEU-FC1C471` is 12.50 mm seated height. Same 10 mm diameter as assumed,
  so the **H3 clearance caveat below still applies unchanged**.

**Notes on the two module lines (10 and 11):** the S3-Zeros are socketed, not
soldered, so each module needs a 1×9 male strip in each of its two pad rows
(line 11) mating with a 1×9 female strip on the carrier (line 10) — 4 strips of
each per board. Board holes are drilled 1.0 mm so a 0.64 mm square pin
(0.905 mm diagonal) passes.

**H3 caveat:** the bottom-left M3 hole sits close to C1's body — use a
low-profile screw head or a washer-free fixing there.

## Library provenance

The ESP32-S3-Zero symbol and footprint come from
<https://github.com/jtomka/kicad-esp32-s3-zero> and are vendored into the project
at `kbdrelay-carrier/symbols/` and `kbdrelay-carrier/footprints/kbdrelay.pretty/`,
registered through the project `sym-lib-table` / `fp-lib-table` with `${KIPRJMOD}`
so the repo is self-contained.

⚠ That upstream repo contains **no LICENSE file**, so its redistribution terms are
unstated. Fine for private use; clarify with the author before publishing the
board files.

## Ordering notes

- **Cheapest-that-meets-spec** per the project constitution: every part here is a
  jellybean — an industry-standard, second-sourced commodity part that many
  vendors make interchangeably, so it's always in stock and costs pennies.
- Resistors: 1/4 W carbon film is fine everywhere. Nothing here dissipates
  meaningful power (worst case a 1 k UART series R at ~1 mW).
- D1 alternates, in order of preference if VBUS headroom is tight:
  **SB560 > SB540 > 1N5817 > 1N5819**. Higher-current Schottkys have a *lower*
  forward drop at our ~0.3 A, which is exactly what we want.

## Why 0.9 A and not 0.5 A (F1)

A 0.5 A PPTC looks like the obvious pick for a 500 mA USB port. It isn't, for two
reasons that only show up in the datasheet's fine print:

- **Hold current derates with temperature** — 83 % at 40 °C, 76 % at 50 °C. A
  0.5 A part holds only ~0.42 A in a warm enclosure. A USB device may legally
  draw **500 mA**, and the KBD module adds ~60–80 mA, so the legitimate load can
  reach **~0.58 A**. The 0.5 A part would nuisance-trip on a legal keyboard.
  0.90 A derates to ~0.75 A → **29 % margin**.
- **Resistance scales inversely with hold rating**, and that resistance sits in
  series with keyboard VBUS. 60R050 is R₁ₘₐₓ **1.17 Ω**; 60R090 is **0.47 Ω**.

Not taken higher: at 60R110's 2.2 A trip, a typical 5 V brick current-limits
before the fuse acts, moving protection from the fuse to the supply.

## ⚠ Power-budget check — measure this at bring-up

D1's forward drop and F1's resistance both eat keyboard VBUS. USB's floor is
**4.40 V**. Worst case uses R₁ₘₐₓ — which is the honest long-term figure, since a
PPTC's resistance rises with self-heating and drifts up after trip events.

**Typical keyboard (~0.3 A total):**

| Element | Best | Worst |
|---|---|---|
| D1 1N5817 Vf | 0.28 V | 0.35 V |
| F1 60R090 (R × 0.3 A) | 0.06 V | 0.14 V |
| **Total** | 0.34 V | 0.49 V |
| **VBUS from 5.00 V** | 4.66 V ✓ | **4.51 V ✓** |

**Max-draw keyboard (500 mA + module ≈ 0.58 A):**

| Element | Best | Worst |
|---|---|---|
| D1 1N5817 Vf | 0.33 V | 0.40 V |
| F1 60R090 (R × 0.58 A) | 0.12 V | 0.27 V |
| **Total** | 0.45 V | 0.67 V |
| **VBUS from 5.00 V** | 4.55 V ✓ | **4.33 V ✗** |
| **VBUS from 5.25 V** | 4.80 V ✓ | 4.58 V ✓ |

**Conclusion:** with 60R090 a plain 5.00 V supply is fine for ordinary keyboards.
A **max-draw keyboard on worst-case parts still dips below 4.40 V**, so
**feeding J3 at 5.1–5.25 V remains the recommendation** — it is now insurance
rather than a hard requirement.

If a specific keyboard misbehaves, the remaining lever is D1: an **SB540/SB560**
fits the same pads and gives back ~0.1 V.

**Either way: measure loaded keyboard VBUS at bring-up (T-007/T-008). It must
read ≥4.40 V.**

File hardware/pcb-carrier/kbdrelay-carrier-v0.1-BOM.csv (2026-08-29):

Line# | Quantity Per Part Number | Reference Designator | Part Number | Part Description | Package | Type | Manufacturers Name | Manufacturers Part Number | Distributors Part Number | Distributor | Notes
1 | 2 | U1,U2 | ESP32-S3-Zero | ESP32-S3FH4R2 module, USB-C, 2x9 castellated/THT pads. U1 = KBD side, U2 = TGT side. SOCKETED - do not solder module to board. | Module 18.06 x 23.53 mm, 2x9 @ 2.54 mm, 15.24 mm row pitch | Thru-hole | Waveshare | ESP32-S3-Zero | NOT STOCKED | Waveshare direct | CONSIGNED. Not carried by Digi-Key; buy direct from Waveshare.
2 | 1 | D1 | 1N5817 | Schottky rectifier 1 A / 20 V, reverse-polarity protection. Band (cathode) faces the load. | DO-204AL / DO-41 axial (board pads are DO-201AD, 12.70 mm pitch) | Thru-hole | Taiwan Semiconductor | 1N5817 | 1801-1N5817CT-ND | Digi-Key | DESIGN-CRITICAL. Cut Tape, MOQ 1. Drop-in alternates by preference: SB560 > SB540 > 1N5817 > 1N5819.
3 | 1 | C1 | EEU-FC1C471 | Aluminium electrolytic capacitor 470 uF / 16 V, 20%, radial - inrush bulk cap. POLARISED: stripe = negative = GND. | Radial D10.00 mm, 5.00 mm lead spacing, 12.50 mm seated height | Thru-hole | Panasonic Industry | EEU-FC1C471 | P10248-ND | Digi-Key | MPN CORRECTED - see BOM.md. Verified 10.00 mm dia / 5.00 mm LS, matches CP_Radial_D10.0mm_P5.00mm. Bulk, MOQ 1.
4 | 1 | C2 | K104K15X7RF53H5 | Ceramic capacitor 100 nF / 50 V X7R, 10%, radial - HF decoupling | Radial 4.00 x 2.60 mm, 5.00 mm lead spacing, 6.60 mm seated height | Thru-hole | Vishay | K104K15X7RF53H5 | BC3323-ND | Digi-Key | MPN CORRECTED - see BOM.md. Same Vishay K-series, 5.00 mm LS variant. Bulk, MOQ 1.
5 | 1 | F1 | 60R090XU | PPTC resettable fuse 0.90 A hold / 1.80 A trip, 60 V, R1max 0.47 ohm - keyboard VBUS protection | Radial, body 11.2 x 3.1 mm, 5.08 mm lead spacing, 0.51 mm leads | Thru-hole | Littelfuse | 60R090XU | F1923-ND | Digi-Key | DESIGN-CRITICAL. Bulk, MOQ 1. Do NOT substitute 60R050 (0.5 A) - it nuisance-trips a legal 500 mA keyboard and its 1.17 ohm pushes VBUS below the 4.40 V USB floor.
6 | 5 | R1,R2,R3,R4,R5 | CFR-25JB-52-2K2 | Resistor 2.2 kohm +/-5%, 1/4 W carbon film - SPI series resistors (SCK/MOSI/MISO/CS/DATA_READY) | Axial 2.40 x 6.30 mm, DIN0207, 10.16 mm pitch | Thru-hole | YAGEO | CFR-25JB-52-2K2 | 2.2KQBK-ND | Digi-Key | Jellybean. Bulk, MOQ 1. Any 2.2k 1/4 W axial is fine.
7 | 4 | R6,R7,R8,R9 | CFR-25JB-52-1K | Resistor 1 kohm +/-5%, 1/4 W carbon film - UART TX/RX series, 2 per module | Axial 2.40 x 6.30 mm, DIN0207, 10.16 mm pitch | Thru-hole | YAGEO | CFR-25JB-52-1K | 1.0KQBK-ND | Digi-Key | MPN CORRECTED - Yageo suffix is -1K, not -1K0. Bulk, MOQ 1.
8 | 1 | J3 | PREC002SAAN-RC | Pin header 1x2, 2.54 mm, vertical - 5 V input. Pin 1 = +5 V, pin 2 = GND. | THT header 1x2 @ 2.54 mm | Thru-hole | Sullins Connector Solutions | PREC002SAAN-RC | 35-PREC002SAAN-RC-ND | Digi-Key | Bulk, MOQ 1. Or cut from a breakaway strip.
9 | 2 | J1,J2 | PREC003SAAN-RC | Pin header 1x3, 2.54 mm, vertical - debug UART. Pin1 = module TX, pin2 = module RX, pin3 = GND. | THT header 1x3 @ 2.54 mm | Thru-hole | Sullins Connector Solutions | PREC003SAAN-RC | 35-PREC003SAAN-RC-ND | Digi-Key | Bulk, MOQ 1. NO VCC pin - deliberate (FR-026).
10 | 4 | U1,U2 sockets | PPTC091LFBN-RC | Female header 1x9, 2.54 mm - module sockets, 2 per module | THT socket strip 1x9 @ 2.54 mm | Thru-hole | Sullins Connector Solutions | PPTC091LFBN-RC | S7007-ND | Digi-Key | Tray, MOQ 1. Board holes are drilled 1.0 mm to pass a 0.64 mm square pin (0.905 mm diagonal).
11 | 4 | U1,U2 module pins | PREC009SAAN-RC | Male pin header 1x9, 2.54 mm - soldered into each module's pad rows, 2 per module | THT header strip 1x9 @ 2.54 mm | Thru-hole | Sullins Connector Solutions | PREC009SAAN-RC | 35-PREC009SAAN-RC-ND | Digi-Key | Bulk, MOQ 1. Soldered to the MODULE, not the carrier. Consigned with the modules.
12 | 4 | H1,H2,H3,H4 | M3x8 pan head + nut | Mounting hardware M3 - board corner holes (3.2 mm NPTH) | M3 screw / nut | Hardware | Generic | M3x8 | NOT ASSEMBLED | Any | NOT SOLDERED - do not assemble. H3 (bottom-left) sits close to C1's body: use a low-profile head.

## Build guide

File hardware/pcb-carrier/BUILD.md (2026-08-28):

# kbdrelay carrier board — build & bring-up

Board: **88 × 55 mm**, single-sided (bottom copper only), all through-hole,
**zero wire jumpers**. Two Waveshare ESP32-S3-Zero modules socket onto 0.1"
headers with their USB-C ports overhanging the two short edges, so a keyboard
cable goes in one end and the target cable out the other.

Parts list: `BOM.md` (see the *Purchasing table* section).
Layout is generated by `place.py` + `route.py` — see "Regenerating" at the end.

---

## 1. Fabrication artwork

Everything is in `fab/`:

> ⚠ **Refill the GND zone before every export.** KiCad does not refill
> automatically, and DRC is the only thing that notices. A stale fill bit us
> once already: the pour polygons predated the trace edits and sat 0.15 mm from
> live copper while the rule said 1.4 mm, so the exported artwork would not have
> matched the board. Press `B` (Edit → Fill All Zones), then re-run DRC, then
> export.

> **Board of record is `kbdrelay-carrier-v0.1.kicad_pcb`** (hand-routed:
> 1.0 mm traces, 1.4 mm pour clearance, 1.70 mm module pads, zero jumpers).
> The script-generated `kbdrelay-carrier.kicad_pcb` is a fallback and does NOT
> match it (it has 4 courtyard-overlap DRC errors and still carries the dropped
> power-good LED). Export from `kbdrelay-carrier-v0.1.kicad_pcb` only.

> **Fab outputs live in `hardware/pcb-carrier/fab/` and nowhere else.**
> `fab/gerbers/` (Gerbers + drill), `fab/print/` (1:1 PDFs), `fab/lcd/` (LCD
> bitmaps). KiCad's GUI defaults to writing exports next to the project file,
> which creates a second, stale copy — so the project's plot output directory is
> preset to `../fab/gerbers/`, and the old location is gitignored. If a Plot or
> Drill dialog ever shows a different output path, fix the path rather than
> living with two sets of artwork.

| File | Use |
|---|-----|
| `print/bottom-copper-MIRRORED-toner.pdf` | **Home etch.** Bottom copper, already mirrored for toner transfer. |
| `print/bottom-copper-asviewed.pdf` | Same artwork un-mirrored, for eyeballing against the CAD view. |
| `print/drill-guide.pdf` | Bottom copper + top silk + actual drill shapes — use to find hole centres. |
| `print/assembly-top-silk.pdf` | Component placement / silkscreen, for stuffing the board. |
| `gerbers/` | Standard Gerbers + Excellon drill (+ drill map) if you'd rather order it. |
| `lcd/` | **LCD/photoresist exposure bitmaps** at the Elegoo Mars 4 Ultra's native panel resolution — see below. |

**Print at 100 % / "actual size" — no fit-to-page.** The PDFs are 1:1 on A4.
Sanity check after printing: the board outline must measure **88.0 × 55.0 mm**
and the two module pad rows must be **15.24 mm (0.6")** apart.

### The `BOTTOM` check

There is a `BOTTOM` text item in copper near the lower middle of the board. Once
etched, **hold the board copper-side towards you: it must read `BOTTOM`
correctly.** If it reads mirrored, the artwork was flipped — the whole board is
inside-out and every part will be on the wrong side. Bin it and re-transfer.

### LCD exposure (Elegoo Mars 4 Ultra)

| File | Size | Notes |
|---|---|---|
| `lcd/kbdrelay-carrier_B.Cu_LCD_8520x4320.png` | 8520 × 4320 | **Use this one.** Full panel, board centred. |
| `lcd/..._LCD_8520x4320_MIRRORED.png` | 8520 × 4320 | Same, flipped in X — only if your workflow needs the other handedness. |
| `lcd/..._boardonly_4889x3056.png` | 4889 × 3056 | Board area only, same pitch, for re-compositing. |

- Panel geometry assumed: **8520 × 4320 px over 153.36 × 77.76 mm = exactly
  18.0 µm/px**. The board is 4889 × 3056 px, so it fits with ~32 mm spare in X
  and ~11 mm in Y.
- **White = copper.** Drawn for **negative-acting dry film**: UV hardens the
  resist, hardened resist protects the copper, so white is the copper you keep.
  Only the thin black isolation channels are etched — 0.4 mm clearance is 22 px,
  so there is plenty of margin at this pitch. **If your resist is
  positive-acting, invert it** (`magick in.png -negate out.png`).
- **Pad centres are solid copper — no drill knockouts.** Generated with
  `--drill-shape-opt 0` on purpose: KiCad's default plots the hole, which would
  etch out every pad centre and leave a 0.5 mm ring with nothing to guide the
  drill bit.
- **Handedness check.** The board is exposed copper-side-down on the panel, so
  the on-screen image is what you see from the copper side after flipping. With
  the recommended un-mirrored file the `BOTTOM` label reads **backwards in the
  slicer preview** and correctly on the finished copper. If it reads correctly
  on screen, you have the mirrored file loaded.
- Registration is computed, not eyeballed: cropped from a 1411 dpi render at the
  board's known sheet origin (104.5, 77.5 mm), verified against the plotted
  outline measuring 88.09 × 55.10 mm.
- Regenerate with the recipe in `make_lcd_art.sh`.

### Clearance / etch tolerance

Two independent knobs, both on `route.py`:

| Flag | Default | Effect |
|---|---|---|
| `--zone-clearance=` | **0.8 mm** | Gap from the GND pour to every trace and pad. **Free tolerance** — raising it only makes the fill retreat, routing is untouched. |
| `--clearance=` | **0.5 mm** | Trace-to-trace and trace-to-pad gap. Costs routability; still routes with zero jumpers at 0.5. |

As-built minimum copper gaps (measured on the board, real pad shapes):

| Feature | Gap |
|---|-----|
| Pour to anything | 0.80 mm |
| Trace to trace | 0.70 mm |
| Trace to pad (different nets) | 0.52 mm |
| **Pad to pad — adjacent module pins** | **0.54 mm ← tightest feature on the board** |

**0.54 mm is the number your process has to resolve**, and no clearance setting
can improve it: it is fixed geometry (2.54 mm pin pitch minus 2.0 mm pads). If
that gap turns out to be marginal in practice, the lever is the module pad
diameter in `footprints/kbdrelay.pretty/ESP32-S3-Zero-Socketed.kicad_mod` —
2.0 mm → 1.8 mm buys 0.74 mm of gap, at the cost of dropping the annular ring
from 0.5 mm to 0.4 mm on a 1.0 mm drill.

### Where a bad etch actually hurts

All 32 of the tightest gaps on this board are between adjacent module pins
(0.54 mm). **Only 9 of them matter electrically** — the rest are next to pins
that are unconnected on the carrier, where a bridge is harmless. Regenerate this
list with `bridge_risk.py`.

Inspect these nine under magnification, and meter them **before** seating any
module:

| Pair | Nets | If bridged |
|---|---|---|
| U1.1 – U1.2 | +5V_KBD / GND | **dead short of the 5 V rail** |
| U1.7 – U1.8 | SCK / MOSI | SPI link dead |
| U1.8 – U1.9 | MOSI / MISO | SPI link dead |
| U1.10 – U1.11 | CS / DATA_READY | SPI link dead |
| U1.17 – U1.18 | KBD UART RX / TX | console dead |
| U2.7 – U2.8 | SCK / MOSI | SPI link dead |
| U2.8 – U2.9 | MOSI / MISO | SPI link dead |
| U2.10 – U2.11 | CS / DATA_READY | SPI link dead |
| U2.17 – U2.18 | TGT UART RX / TX | console dead |

Good news on the one that could damage the target: **U2.1 (the TGT module's 5 V
pin) is unconnected on the carrier**, so a bridge from it to U2.2 (GND) shorts
nothing while the board is bare. It does, however, become a path from the
*target's* USB 5 V to GND once the module is seated — so U2.1–U2.2 is still
worth a meter check before you plug into anything you care about.

If bridging turns out to be the recurring failure, the lever is shrinking the
**unconnected** module pads (U1: 3,4,5,6,12–16; U2: 1,3,4,5,6,12–16) — they are
mechanical only, so their pads can drop to ~1.7 mm and widen those gaps to
~0.69 mm at zero electrical cost.

---

## 2. Drilling

78 holes, five sizes. Drill from the copper side using `drill-guide.pdf`.

| Drill | Count | Where |
|---|---:|---|
| 0.80 mm | 22 | R1–R9, R12 (axial resistors), C2 |
| 0.90 mm | 2 | D2 (LED) |
| 1.00 mm | 48 | U1, U2 (18 each), C1, F1, J1, J2, J3 |
| 1.60 mm | 2 | D1 (Schottky, DO-201AD pads) |
| 3.20 mm | 4 | H1–H4 mounting holes (non-plated) |

The module and fuse pads are deliberately **2.0 mm pads on 1.0 mm drills** —
that leaves a 0.5 mm annular ring, which survives hand drilling, and passes a
0.64 mm square header pin (0.905 mm diagonal) that a 0.762 mm hole will not.
**Have a 1.0 mm bit on hand**; it does the bulk of the work.

There are **no vias and no plated holes**. Every connection is on the bottom
copper; the top side is bare. That means **every component lead is soldered on
the bottom side only** — including the header pins.

---

## 3. Assembly order

Lowest parts first so the board sits flat while soldering:

1. **R1–R9, R12** — 10 axial resistors, lying flat, 10.16 mm pitch.
   - R1–R5 = **2.2 kΩ** (SPI series), the column at mid-board, top to bottom:
     R5 (DRDY) / R4 (CS) / R3 (MISO) / R2 (MOSI) / R1 (SCK).
   - R6–R9 = **1 kΩ** (UART series), R12 = **1 kΩ** (LED limit).
   - Getting 2.2 k and 1 k swapped will not destroy anything, but SPI will be
     marginal and the LED dim — check the colour bands before soldering.
2. **D1 — 1N5817 Schottky. POLARITY CRITICAL.** The **banded end (cathode) faces
   LEFT**, toward F1 and the modules. The unbanded (anode) end faces right,
   toward J3 / 5 V in. Backwards = no power at all (the safe failure).
3. **D2 — LED. POLARITY.** Cathode (short leg / flat side) faces **right**,
   toward R12. Anode faces left toward the fused rail.
4. **C2** — 100 nF disc, not polarised.
5. **F1** — 60R090 PPTC, not polarised, 5.08 mm pitch, straight leads.
6. **C1 — 470 µF electrolytic. POLARITY CRITICAL.** The **stripe (negative) faces
   RIGHT**, toward C2. Backwards on 5 V will vent it.
7. **J3** (1×2, 5 V in), **J1** and **J2** (1×3 UART) — vertical pin headers.
   - J3: pin 1 = **+5 V** (silk `+`), pin 2 = **GND** (silk `G`).
   - J1/J2: pin 1 = module **TX**, pin 2 = **RX**, pin 3 = **GND**.
     There is deliberately **no VCC pin** on the UART headers.
8. **Module sockets** — four 1×9 female strips, 15.24 mm apart per module.
   Seat them square: solder one end pin, check they sit flat, then do the rest.
9. **M3 hardware** last. Note H3 (bottom-left) sits close to C1's body — use a
   low-profile screw head there.

The modules themselves need four 1×9 **male** strips soldered into their own pad
rows before they can plug in.

### Keep clear

Both modules' onboard **BOOT and RESET buttons must stay reachable with the
modules seated** — that is how firmware gets flashed in situ (there is no
soft-reset header; the shared-GP9 idea was removed by design amendment because
`esp_restart()` cannot enter download mode). Don't add tall parts beside them.

---

## 4. Bare-board bring-up — do this before seating any module

With **no modules fitted**, meter in hand:

1. **Continuity / isolation**
   - GND is common across J1.3, J2.3, J3.2, C1.2, C2.2, U1 pad 2, U2 pad 2.
   - **U2 pad 1 (TGT 5 V) must be isolated from everything** — the target's USB
     powers TGT, and the two 5 V domains are never merged (FR-011). Only GND is
     shared. Confirm this with a meter; it is the one mistake that could
     backfeed a target machine.
   - SPI pin-to-pin, one series resistor per line:
     U1.7 → R1 → U2.7 (SCK / GP4), U1.8 → R2 → U2.8 (MOSI / GP5),
     U1.9 → R3 → U2.9 (MISO / GP6), U1.10 → R4 → U2.10 (CS / GP7),
     U1.11 → R5 → U2.11 (DATA_READY / GP8).
     Each resistor should read ~2.2 kΩ pin-to-pin and nothing should read short.
   - ⚠ **The two modules' pad rows are mirrored**, because U1 and U2 are rotated
     opposite ways so both USB-C ports face outward. U1's pads 1–9 are its
     **lower** row and 10–18 its upper; U2's pads 1–9 are its **upper** row and
     10–18 its lower. Count pins from the square pad 1 marker on the silkscreen,
     not by row position.
2. **Apply +5 V to J3** (bench supply, current-limited to ~200 mA).
   - Power-good LED lights.
   - Voltage at U1 pad 1 ≈ input − ~0.3 V (the Schottky drop).
3. **Reverse the supply on J3.** Nothing should light, nothing should get warm,
   and no rail should appear. Then put it back the right way round.
4. **Measure F1's in-circuit DC resistance** (expect 0.2–0.5 Ω, up to ~1.2 Ω on
   a cold worst-case part). Write the number down — it feeds the VBUS budget.

## 5. Populated bring-up

Seat both modules (KBD = U1, left; TGT = U2, right), flash the v1 firmware, then
reproduce **AC1–AC5**: typing passes through, Caps/Num/Scroll-Lock LEDs come back
from the target, hot-plug works, watchdog recovers.

Then the fault and margin tests:

- **Keyboard VBUS under load must measure ≥ 4.40 V** with the highest-draw
  keyboard you own. This is the one number that can fail the design: worst-case
  D1 + F1 drop is 0.67 V at 0.58 A, which puts a 5.00 V feed at 4.33 V. If you
  are low, **feed J3 at 5.1–5.25 V** (recommended anyway) or fit an **SB540 /
  SB560** in D1's place — same pads, ~0.1 V less drop.
- High-inrush keyboard enumerates on the first plug-in (this is what C1 is for).
- A brief keyboard-VBUS short trips F1 and it recovers when removed.
- **All power-up orders** work, especially KBD-first → TGT cold-starts later.
- A powered USB-UART debug adapter must not back-power either board.

---

## Regenerating the layout

The board is scripted; don't hand-edit `kbdrelay-carrier.kicad_pcb`.

```sh
PY=/Applications/KiCad/KiCad.app/Contents/Frameworks/Python.framework/Versions/Current/bin/python3
cd hardware/pcb-carrier
$PY place.py                 # placement, outline, M3 holes, silkscreen, sheet centering
$PY route.py --attempts=60   # B.Cu maze routing + GND pour (deterministic, --seed=7)
kicad-cli pcb drc --format json -o /tmp/drc.json kbdrelay-carrier/kbdrelay-carrier.kicad_pcb
```

`route.py` prints the jumper list — **it should say 0 jumpers.** If a change
pushes it above zero, the wire links it wants are listed by pad pair, and they
belong in this document before anyone etches.

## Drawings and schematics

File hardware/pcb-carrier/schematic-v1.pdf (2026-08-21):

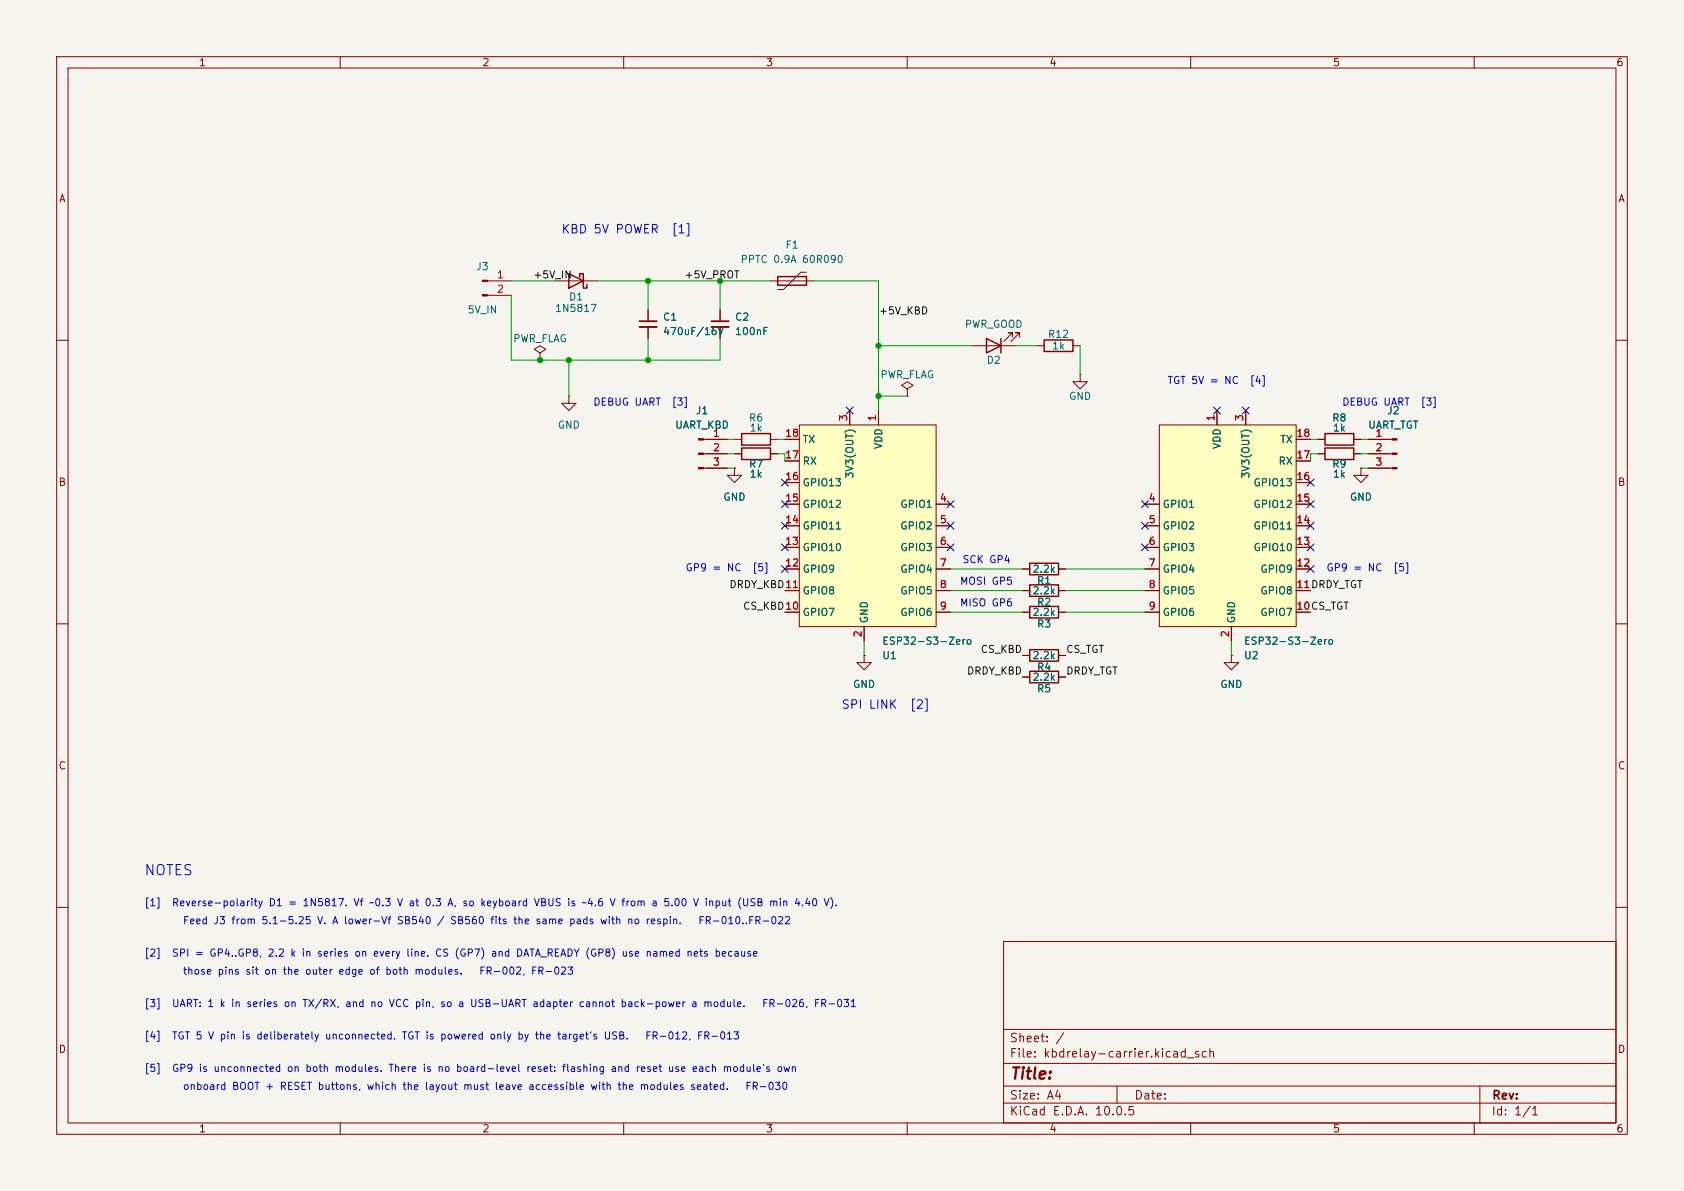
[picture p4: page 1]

KBD 5V POWER [1] DEBUG UART [3]

[1] Reverse-polarity D1 = 1N5817. Vf ~0.3 V at 0.3 A, so keyboard VBUS is ~4.6 V from a 5.00 V input (USB min 4.40 V).

[2] SPI = GP4..GP8, 2.2 k in series on every line. CS (GP7) and DATA_READY (GP8) use named nets because

[5] GP9 is unconnected on both modules. There is no board-level reset: flashing and reset use each module's own

Size: A4 | Rev:
KiCad E.D.A. 10.0.5 | Id: 1/1

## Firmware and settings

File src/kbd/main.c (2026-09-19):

/*
 * KBD firmware — USB host bring-up (subset of task T4).
 *
 * Enumerates a USB keyboard plugged into KBD's USB-C port, requests boot
 * protocol (FR1.3), supports keyboards that sit behind an internal hub
 * (FR1.2, via CONFIG_USB_HOST_HUBS_SUPPORTED), and logs each raw 8-byte boot
 * report over UART. Hot-plug is handled (FR1.4).
 *
 * Onboard WS2812 status LED:
 *   - powered, no keyboard  -> slow blue blink (~1 Hz)
 *   - keyboard connected     -> solid green
 *
 * No SPI / bridge_proto yet — this proves we can read the keyboard and see its
 * reports on the serial monitor. Forwarding those reports over SPI is next (T4).
 *
 * Console is on UART0 (TX/RX pads) because the USB-C port is the keyboard
 * host — view logs via a 3.3 V USB-UART adapter at 115200 baud.
 */
#include <stdio.h>
#include <string.h>
#include "freertos/FreeRTOS.h"
#include "freertos/task.h"
#include "freertos/queue.h"
#include "esp_log.h"
#include "esp_intr_alloc.h"
#include "driver/spi_master.h"
#include "driver/gpio.h"
#include "esp_rom_sys.h"
#include "usb/usb_host.h"
#include "usb/hid_host.h"
#include "led_strip.h"
#include "bridge_proto.h"

static const char *TAG = "kbd";

#define WS2812_GPIO 21

/* SPI master link to TGT (see plan.md wiring). */
#define PIN_SCK     4
#define PIN_MOSI    5
#define PIN_MISO    6
#define PIN_CS      7
#define PIN_DR      8            /* DATA_READY: input (LED backchannel, later) */
#define SPI_HOST_ID SPI2_HOST
#define SPI_CLOCK_HZ 250000
#define HEARTBEAT_MS 25

static spi_device_handle_t s_spi;
static QueueHandle_t s_report_queue;   /* items: 8-byte boot keyboard reports */

static QueueHandle_t s_event_queue;
static led_strip_handle_t s_led;

/* Handles of interfaces we've identified and started as keyboards. Used both
 * for the status LED (any present => green) and to distinguish a real keyboard
 * unplug from the DISCONNECTED event that fires when we close a non-keyboard
 * interface. Mutated from the app task (connect) and HID driver task
 * (disconnect); guarded by a spinlock. */
#define MAX_KB_IFACES 8
#define KB_REPORT_MAX 16

typedef struct {
    hid_host_device_handle_t handle;  /* NULL = free slot */
    uint8_t last[KB_REPORT_MAX];      /* previous report, for change detection */
    size_t last_len;
} kb_slot_t;

static kb_slot_t s_kb[MAX_KB_IFACES];
static volatile int s_kb_ifaces;
static portMUX_TYPE s_kb_lock = portMUX_INITIALIZER_UNLOCKED;

static void kb_track_add(hid_host_device_handle_t h)
{
    portENTER_CRITICAL(&s_kb_lock);
    for (int i = 0; i < MAX_KB_IFACES; i++) {
        if (s_kb[i].handle == NULL) {
            s_kb[i].handle = h;
            s_kb[i].last_len = 0;
            s_kb_ifaces++;
            break;
        }
    }
    portEXIT_CRITICAL(&s_kb_lock);
}

/* Returns true if the handle was a tracked keyboard (and removes it). */
static bool kb_track_remove(hid_host_device_handle_t h)
{
    bool found = false;
    portENTER_CRITICAL(&s_kb_lock);
    for (int i = 0; i < MAX_KB_IFACES; i++) {
        if (s_kb[i].handle == h) {
            s_kb[i].handle = NULL;
            s_kb_ifaces--;
            found = true;
            break;
        }
    }
    portEXIT_CRITICAL(&s_kb_lock);
    return found;
}

/* Copy the current tracked keyboard handles out (for use outside the lock). */
static int kb_snapshot_handles(hid_host_device_handle_t *out, int max)
{
    int c = 0;
    portENTER_CRITICAL(&s_kb_lock);
    for (int i = 0; i < MAX_KB_IFACES && c < max; i++) {
        if (s_kb[i].handle != NULL) {
            out[c++] = s_kb[i].handle;
        }
    }
    portEXIT_CRITICAL(&s_kb_lock);
    return c;
}

/* Deliver a keyboard LED bitmap (Caps/Num/Scroll) to every open keyboard
 * interface via HID Set Report (FR2.2). Deduped by the caller. */
static void kb_set_leds(uint8_t leds)
{
    hid_host_device_handle_t handles[MAX_KB_IFACES];
    int n = kb_snapshot_handles(handles, MAX_KB_IFACES);
    uint8_t buf[1] = { leds };
    for (int i = 0; i < n; i++) {
        esp_err_t e = hid_class_request_set_report(handles[i], HID_REPORT_TYPE_OUTPUT, 0, buf, 1);
        if (e != ESP_OK) {
            ESP_LOGW(TAG, "set LED report failed: %s", esp_err_to_name(e));
        }
    }
}

/* True if this report differs from the last one for this interface (updating
 * the stored copy). Collapses free-running streams to one event per change —
 * the bridge only cares about changes anyway (FR3.2). */
static bool kb_report_changed(hid_host_device_handle_t h, const uint8_t *data, size_t len)
{
    bool changed = true;
    portENTER_CRITICAL(&s_kb_lock);
    for (int i = 0; i < MAX_KB_IFACES; i++) {
        if (s_kb[i].handle == h) {
            size_t n = (len > KB_REPORT_MAX) ? KB_REPORT_MAX : len;
            if (s_kb[i].last_len == n && memcmp(s_kb[i].last, data, n) == 0) {
                changed = false;
            } else {
                memcpy(s_kb[i].last, data, n);
                s_kb[i].last_len = n;
            }
            break;
        }
    }
    portEXIT_CRITICAL(&s_kb_lock);
    return changed;
}

typedef struct {
    hid_host_device_handle_t handle;
    hid_host_driver_event_t event;
} app_event_t;

/*
 * Walk a HID report descriptor and report whether it declares a keyboard
 * (Usage Page = Generic Desktop 0x01, Usage = Keyboard 0x06 at a Collection).
 * This is more robust than trusting the interface protocol byte: composite /
 * non-boot keyboards report sub_class=0/proto=0 yet still carry a keyboard
 * usage here (FR1.2, plan.md non-boot-descriptor risk).
 */
static bool descriptor_is_keyboard(const uint8_t *d, size_t len)
{
    if (d == NULL) {
        return false;
    }
    uint16_t usage_page = 0;
    uint16_t usage = 0;
    size_t i = 0;
    while (i < len) {
        const uint8_t item = d[i++];
        uint8_t size = item & 0x03;          /* bSize code: 0,1,2,3 -> 0,1,2,4 */
        if (size == 3) {
            size = 4;
        }
        uint32_t data = 0;
        for (uint8_t b = 0; b < size && i < len; b++) {
            data |= (uint32_t)d[i++] << (8 * b);
        }
        switch (item & 0xFC) {            /* bTag | bType, size bits masked off */
        case 0x04:                        /* Usage Page (global) */
            usage_page = (uint16_t)data;
            break;
        case 0x08:                        /* Usage (local) */
            usage = (uint16_t)data;
            break;
        case 0xA0:                        /* Collection */
            if (usage_page == 0x01 && usage == 0x06) {
                return true;              /* Generic Desktop / Keyboard */
            }
            break;
        default:
            break;
        }
    }
    return false;
}

/* Drives the status LED based on keyboard-connected state. */
static void led_task(void *arg)
{
    (void)arg;
    bool blink_on = false;
    while (1) {
        if (s_kb_ifaces > 0) {
            led_strip_set_pixel(s_led, 0, 0, 20, 0); /* solid green: connected */
            led_strip_refresh(s_led);
            vTaskDelay(pdMS_TO_TICKS(150));
        } else {
            blink_on = !blink_on;                    /* slow blue blink: waiting */
            if (blink_on) {
                led_strip_set_pixel(s_led, 0, 0, 0, 12);
            } else {
                led_strip_clear(s_led);
            }
            led_strip_refresh(s_led);
            vTaskDelay(pdMS_TO_TICKS(500));
        }
    }
}

/* SPI master: send a KEY_REPORT when a key changes, else a HEARTBEAT every
 * 25 ms so TGT's watchdog stays satisfied (plan.md SPI Protocol). Each
 * full-duplex exchange also harvests TGT's frame (LED_REPORT handled later). */
static void spi_master_task(void *arg)
{
    (void)arg;
    WORD_ALIGNED_ATTR static uint8_t tx[BRIDGE_FRAME_SIZE];
    WORD_ALIGNED_ATTR static uint8_t rx[BRIDGE_FRAME_SIZE];
    uint8_t seq = 0;
    uint8_t rpt[BRIDGE_PAYLOAD_SIZE];

    while (1) {
        bridge_frame_t f = { .seq = seq++ };
        if (xQueueReceive(s_report_queue, rpt, pdMS_TO_TICKS(HEARTBEAT_MS)) == pdTRUE) {
            f.type = BRIDGE_TYPE_KEY_REPORT;
            memcpy(f.payload, rpt, BRIDGE_PAYLOAD_SIZE);
        } else {
            f.type = BRIDGE_TYPE_HEARTBEAT;
        }
        bridge_encode(&f, tx);

        spi_transaction_t t = {
            .length = BRIDGE_FRAME_SIZE * 8,
            .tx_buffer = tx,
            .rx_buffer = rx,
        };
        /* Soft CS, open-drain: assert (sink low), transact, release (hi-Z).
         * CS is the only link line that would otherwise idle HIGH, and at
         * 2.2k series it back-feeds ~460 uA into an unpowered TGT, parking
         * its 3V3 rail at 1.68 V and defeating power-on reset (measured).
         * Open-drain can only sink, so it cannot inject; TGT supplies the
         * idle pull-up from its own rail. */
        gpio_set_level(PIN_CS, 0);
        esp_rom_delay_us(2);                 /* CS setup before first SCK */
        esp_err_t xfer = spi_device_transmit(s_spi, &t);
        esp_rom_delay_us(2);                 /* CS hold after last SCK */
        gpio_set_level(PIN_CS, 1);
        if (xfer == ESP_OK) {
            bridge_frame_t in;
            if (bridge_decode(rx, &in) && in.type == BRIDGE_TYPE_LED_REPORT) {
                static uint8_t last_leds = 0xFF;
                if (in.payload[0] != last_leds) {
                    last_leds = in.payload[0];
                    ESP_LOGI(TAG, "LED state <- 0x%02X", in.payload[0]);
                    kb_set_leds(in.payload[0]);
                }
            }
        }
    }
}

/* USB Host Library event pump. */
static void usb_lib_task(void *arg)
{
    (void)arg;
    while (1) {
        uint32_t flags;
        usb_host_lib_handle_events(portMAX_DELAY, &flags);
        if (flags & USB_HOST_LIB_EVENT_FLAGS_NO_CLIENTS) {
            usb_host_device_free_all();
        }
    }
}

/* Per-interface events: input reports + disconnect. Runs in HID driver task. */
static void hid_iface_cb(hid_host_device_handle_t handle,
                         const hid_host_interface_event_t event, void *arg)
{
    (void)arg;
    hid_host_dev_params_t params;
    hid_host_device_get_params(handle, &params);

    switch (event) {
    case HID_HOST_INTERFACE_EVENT_INPUT_REPORT: {
        uint8_t data[KB_REPORT_MAX];
        size_t len = 0;
        if (hid_host_device_get_raw_input_report_data(handle, data, sizeof(data), &len) == ESP_OK) {
            if (!kb_report_changed(handle, data, len)) {
                break; /* identical to previous report -> ignore (dedup floods) */
            }
            char hex[3 * sizeof(data) + 1];
            int p = 0;
            for (size_t i = 0; i < len && i < sizeof(data); i++) {
                p += sprintf(hex + p, "%02X ", data[i]);
            }
            /* Boot keyboard report layout: [modifiers][reserved][keycode x6] */
            ESP_LOGI(TAG, "key report iface %d (%d B): %s", params.iface_num, (int)len, hex);

            /* Forward the (up to) 8-byte boot report to TGT over SPI. */
            uint8_t rpt[BRIDGE_PAYLOAD_SIZE] = {0};
            size_t n = (len < BRIDGE_PAYLOAD_SIZE) ? len : BRIDGE_PAYLOAD_SIZE;
            memcpy(rpt, data, n);
            if (s_report_queue) {
                xQueueSend(s_report_queue, rpt, 0);
            }
        }
        break;
    }
    case HID_HOST_INTERFACE_EVENT_DISCONNECTED:
        /* This fires both on real unplug and when we close a non-keyboard
         * interface. Only act (and close) if it was a tracked keyboard. */
        if (kb_track_remove(handle)) {
            ESP_LOGI(TAG, "keyboard disconnected (iface %d)", params.iface_num);
            hid_host_device_close(handle);
            /* Immediately forward an all-keys-up report so nothing sticks on the
             * target, rather than waiting for TGT's watchdog (FR4.2). */
            uint8_t zero[BRIDGE_PAYLOAD_SIZE] = {0};
            if (s_report_queue) {
                xQueueSend(s_report_queue, zero, 0);
            }
        }
        break;
    case HID_HOST_INTERFACE_EVENT_TRANSFER_ERROR:
        ESP_LOGW(TAG, "transfer error (iface %d)", params.iface_num);
        break;
    default:
        break;
    }
}

/* Driver-level events (device connected). Marshal to the app task. */
static void hid_driver_cb(hid_host_device_handle_t handle,
                          const hid_host_driver_event_t event, void *arg)
{
    (void)arg;
    const app_event_t e = { .handle = handle, .event = event };
    xQueueSend(s_event_queue, &e, 0);
}

static void handle_connected(hid_host_device_handle_t handle)
{
    hid_host_dev_params_t params;
    ESP_ERROR_CHECK(hid_host_device_get_params(handle, &params));

    const hid_host_device_config_t cfg = {
        .callback = hid_iface_cb,
        .callback_arg = NULL,
    };
    ESP_ERROR_CHECK(hid_host_device_open(handle, &cfg));

    /* Decide if this interface is a keyboard: prefer the boot protocol byte,
     * fall back to parsing the report descriptor for non-boot keyboards. */
    bool is_keyboard = (params.proto == HID_PROTOCOL_KEYBOARD);
    const char *how = "boot-proto";
    if (!is_keyboard) {
        size_t desc_len = 0;
        const uint8_t *desc = hid_host_get_report_descriptor(handle, &desc_len);
        if (descriptor_is_keyboard(desc, desc_len)) {
            is_keyboard = true;
            how = "report-desc";
        }
    }

    if (!is_keyboard) {
        ESP_LOGI(TAG, "ignoring non-keyboard iface %d (sub_class=%d proto=%d)",
                 params.iface_num, params.sub_class, params.proto);
        hid_host_device_close(handle);
        return;
    }

    /* If the device offers boot protocol, use it for the clean 8-byte report
     * (FR1.3). Otherwise consume its report-protocol reports as-is. */
    if (params.sub_class == HID_SUBCLASS_BOOT_INTERFACE) {
        ESP_ERROR_CHECK(hid_class_request_set_protocol(handle, HID_REPORT_PROTOCOL_BOOT));
    }
    /* Set Idle = 0 => report only on change, for boot AND report-protocol
     * keyboards (stops held-key report floods). Some devices STALL this
     * request; that's non-fatal. */
    esp_err_t idle_err = hid_class_request_set_idle(handle, 0, 0);
    if (idle_err != ESP_OK) {
        ESP_LOGW(TAG, "set_idle not honored (iface %d): %s",
                 params.iface_num, esp_err_to_name(idle_err));
    }

    ESP_ERROR_CHECK(hid_host_device_start(handle));
    kb_track_add(handle);

    ESP_LOGI(TAG, "keyboard iface started: addr=%d iface=%d sub_class=%d proto=%d (via %s)",
             params.addr, params.iface_num, params.sub_class, params.proto, how);
}

void app_main(void)
{
    led_strip_config_t strip_cfg = {
        .strip_gpio_num = WS2812_GPIO,
        .max_leds = 1,
        /* This board's onboard WS2812 uses RGB order (not the usual GRB),
         * so set the format explicitly or red/green come out swapped. */
        .color_component_format = LED_STRIP_COLOR_COMPONENT_FMT_RGB,
    };
    led_strip_rmt_config_t rmt_cfg = { .resolution_hz = 10 * 1000 * 1000 };
    ESP_ERROR_CHECK(led_strip_new_rmt_device(&strip_cfg, &rmt_cfg, &s_led));
    led_strip_clear(s_led);
    xTaskCreate(led_task, "led", 2048, NULL, 2, NULL);

    /* SPI master link to TGT. */
    s_report_queue = xQueueCreate(16, BRIDGE_PAYLOAD_SIZE);
    const spi_bus_config_t buscfg = {
        .mosi_io_num = PIN_MOSI,
        .miso_io_num = PIN_MISO,
        .sclk_io_num = PIN_SCK,
        .quadwp_io_num = -1,
        .quadhd_io_num = -1,
    };
    /* CS driven by hand, open-drain, released (hi-Z) at idle. */
    const gpio_config_t cs_cfg = {
        .pin_bit_mask = 1ULL << PIN_CS,
        .mode = GPIO_MODE_OUTPUT_OD,
    };
    ESP_ERROR_CHECK(gpio_config(&cs_cfg));
    gpio_set_level(PIN_CS, 1);

    ESP_ERROR_CHECK(spi_bus_initialize(SPI_HOST_ID, &buscfg, SPI_DMA_CH_AUTO));
    const spi_device_interface_config_t devcfg = {
        .clock_speed_hz = SPI_CLOCK_HZ,
        .mode = 0,
        .spics_io_num = -1,          /* soft CS: see spi_master_task */
        .queue_size = 3,
    };
    ESP_ERROR_CHECK(spi_bus_add_device(SPI_HOST_ID, &devcfg, &s_spi));
    xTaskCreate(spi_master_task, "spi", 4096, NULL, 4, NULL);

    const usb_host_config_t host_config = {
        .skip_phy_setup = false,
        .intr_flags = ESP_INTR_FLAG_LEVEL1,
    };
    ESP_ERROR_CHECK(usb_host_install(&host_config));
    xTaskCreatePinnedToCore(usb_lib_task, "usb_lib", 4096, NULL, 2, NULL, 0);

    s_event_queue = xQueueCreate(10, sizeof(app_event_t));

    const hid_host_driver_config_t driver_cfg = {
        .create_background_task = true,
        .task_priority = 5,
        .stack_size = 4096,
        .core_id = 0,
        .callback = hid_driver_cb,
        .callback_arg = NULL,
    };
    ESP_ERROR_CHECK(hid_host_install(&driver_cfg));

    ESP_LOGI(TAG, "KBD USB host ready — plug a keyboard into KBD's USB-C port");

    app_event_t e;
    while (1) {
        if (xQueueReceive(s_event_queue, &e, portMAX_DELAY)) {
            if (e.event == HID_HOST_DRIVER_EVENT_CONNECTED) {
                handle_connected(e.handle);
            }
        }
    }
}

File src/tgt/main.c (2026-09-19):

/*
 * TGT firmware — SPI slave + boot-keyboard replay (task T3).
 *
 * Presents a vanilla USB 1.1 boot keyboard to the target (FR3.1) and replays
 * KEY_REPORT frames received over SPI from KBD, verbatim (FR3.2). A watchdog
 * releases all keys if the link goes quiet, so keys never stick (FR4.1).
 *
 * SPI: slave, mode 0, fixed 12-byte bridge_proto frames. KBD is master.
 * Console on UART0 (USB-C is the keyboard the target sees).
 *
 * Status LED (onboard WS2812, RGB order):
 *   - link alive (recent valid frame) -> solid green
 *   - link quiet / watchdog            -> slow red blink
 */
#include <string.h>
#include "freertos/FreeRTOS.h"
#include "freertos/task.h"
#include "esp_log.h"
#include "esp_timer.h"
#include "driver/spi_slave.h"
#include "driver/gpio.h"
#include "tinyusb.h"
#include "tinyusb_default_config.h"
#include "class/hid/hid_device.h"
#include "led_strip.h"
#include "bridge_proto.h"

static const char *TAG = "tgt";

#define WS2812_GPIO   21
#define PIN_SCK       4
#define PIN_MOSI      5
#define PIN_MISO      6
#define PIN_CS        7
#define PIN_DR        8            /* DATA_READY: output (LED backchannel, later) */
#define SPI_HOST_ID   SPI2_HOST
#define WATCHDOG_US   75000        /* FR4.1: release keys well within 100 ms */

/* ---- USB descriptors: single boot-protocol keyboard interface (FR3.1) --- */

static const uint8_t hid_report_descriptor[] = {
    TUD_HID_REPORT_DESC_KEYBOARD()
};

enum { ITF_NUM_HID = 0, ITF_NUM_TOTAL };
#define TUSB_DESC_TOTAL_LEN (TUD_CONFIG_DESC_LEN + TUD_HID_DESC_LEN)
#define EPNUM_HID 0x81

static const uint8_t hid_configuration_descriptor[] = {
    TUD_CONFIG_DESCRIPTOR(1, ITF_NUM_TOTAL, 0, TUSB_DESC_TOTAL_LEN,
                          TUSB_DESC_CONFIG_ATT_REMOTE_WAKEUP, 100),
    TUD_HID_DESCRIPTOR(ITF_NUM_HID, 0, HID_ITF_PROTOCOL_KEYBOARD,
                       sizeof(hid_report_descriptor), EPNUM_HID, 8, 10),
};

static const tusb_desc_device_t device_descriptor = {
    .bLength            = sizeof(tusb_desc_device_t),
    .bDescriptorType    = TUSB_DESC_DEVICE,
    .bcdUSB             = 0x0110,
    .bDeviceClass       = 0x00,
    .bDeviceSubClass    = 0x00,
    .bDeviceProtocol    = 0x00,
    .bMaxPacketSize0    = CFG_TUD_ENDPOINT0_SIZE,
    .idVendor           = 0x303A,
    .idProduct          = 0x4004,
    .bcdDevice          = 0x0100,
    .iManufacturer      = 0x01,
    .iProduct           = 0x02,
    .iSerialNumber      = 0x03,
    .bNumConfigurations = 0x01,
};

static const char *string_descriptor[] = {
    (const char[]){0x09, 0x04},
    "kbdrelay",
    "kbdrelay TGT keyboard",
    "000001",
};

uint8_t const *tud_hid_descriptor_report_cb(uint8_t instance)
{
    (void)instance;
    return hid_report_descriptor;
}

uint16_t tud_hid_get_report_cb(uint8_t instance, uint8_t report_id,
                               hid_report_type_t report_type,
                               uint8_t *buffer, uint16_t reqlen)
{
    (void)instance; (void)report_id; (void)report_type; (void)buffer; (void)reqlen;
    return 0;
}

/* Latest keyboard LED bitmap from the target host, pending forward to KBD. */
static volatile uint8_t s_led_state;
static volatile bool s_led_pending;

void tud_hid_set_report_cb(uint8_t instance, uint8_t report_id,
                           hid_report_type_t report_type,
                           uint8_t const *buffer, uint16_t bufsize)
{
    /* Host LED output report (Caps/Num/Scroll) -> queue it for KBD (FR2.2). */
    (void)instance; (void)report_id;
    if (report_type == HID_REPORT_TYPE_OUTPUT && bufsize >= 1) {
        s_led_state = buffer[0];
        s_led_pending = true;
        gpio_set_level(PIN_DR, 1);   /* tell KBD an LED report is waiting */
    }
}

/* ---- application ------------------------------------------------------- */

static led_strip_handle_t s_led;
static volatile int64_t s_last_valid_us;

static void led_task(void *arg)
{
    (void)arg;
    bool blink = false;
    while (1) {
        bool alive = (esp_timer_get_time() - s_last_valid_us) < WATCHDOG_US;
        if (alive) {
            led_strip_set_pixel(s_led, 0, 0, 20, 0);   /* solid green: link up */
            led_strip_refresh(s_led);
            vTaskDelay(pdMS_TO_TICKS(120));
        } else {
            blink = !blink;                             /* red blink: no link */
            if (blink) {
                led_strip_set_pixel(s_led, 0, 20, 0, 0);
            } else {
                led_strip_clear(s_led);
            }
            led_strip_refresh(s_led);
            vTaskDelay(pdMS_TO_TICKS(300));
        }
    }
}

static bool send_hid(const uint8_t report8[8])
{
    if (tud_mounted() && tud_hid_ready()) {
        return tud_hid_report(0, report8, 8);
    }
    return false;
}
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

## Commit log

2026-08-10 feat: kbdrelay v1 — transparent USB HID keyboard bridge (KBD/TGT over SPI)
    Two Waveshare ESP32-S3-Zero boards bridge any USB keyboard into a target as a
    vanilla USB 1.1 boot-protocol keyboard:
    - KBD: USB host + usb_host_hid; identifies keyboards by report descriptor
    (handles boot, composite, and hubbed non-boot keyboards), boot protocol,
    change-detection dedup, SPI master forwarding KEY_REPORTs + 25ms heartbeat.
    - TGT: esp_tinyusb boot keyboard, SPI slave replaying reports verbatim, 75ms
    stuck-key watchdog.
    - bridge_proto: shared 12-byte framed protocol + CRC8, host unit-tested (native).
    - LED backchannel (Caps/Num Lock) TGT->KBD via MISO + DATA_READY.
    Built with PlatformIO + ESP-I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
    [main.c]
2026-08-19 docs: add AGENTS.md + kick off PCB carrier-board spec
    - AGENTS.md: agent onboarding (project status, repo map, build/test via
    Makefile, hardware gotchas, spec-driven conventions, current open task).
    - .specs/pcb-carrier-board/: spec-driven effort for a single-sided, through-hole
    carrier PCB hosting two socketed S3-Zero modules. brainstorm + requirements +
    design approved; tasks drafted. Captures FR5 power rules, back-power/backfeed
    protection (P-FET reverse polarity, bulk cap, polyfuse, 2.2k SPI series R,
    TGT 5V isolation), single-sided home-fab constraints.
    - hardware/pcb-carrier/: KiCad project (kbdrelay-carrier) + concept schematic
    (schematic-concept.svg/png) + README.
    - confi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
    [kbdrelay-carrier.kicad_pcb, kbdrelay-carrier.kicad_sch]
2026-08-21 WIP(pcb): schematic complete + ERC-clean, project libraries, layout placement
    Schematic (T-002) is complete and passes ERC with 0 errors. BOM and BUILD
    drafted. PCB placement done to the agreed landscape form factor; routing
    not started.
    Design amendments (each gated and approved separately):
    - D1: P-FET -> 1N5817 series Schottky. Logic-level THT power P-FETs are
    unsourceable at hobby quantity. Costs ~0.3 V of keyboard VBUS headroom.
    - F1: 0.5 A PPTC -> Littelfuse 60R090 (0.9 A hold / 1.8 A trip). A 0.5 A part
    derates to ~0.42 A at 40 C and would nuisance-trip a legal 500 mA keyboard;
    its 1.17 ohm R1max also pushed VBUS below the 4.40 V USB floor.
    - Shared GP9 soft-reset removed (J4,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
    [kbdrelay-carrier.kicad_pcb, kbdrelay-carrier.kicad_sch]
2026-08-21 feat(pcb): complete single-layer layout — 88x55 mm, zero jumpers, DRC-clean
    Picks up the paused T-004 layout work.
    Fixes a placement bug that made the board unbuildable: both ESP32-S3-Zero
    modules sat entirely off the board (U1 pads at x -20..0, U2 at 122..140 on a
    0-120 mm board). The anchors were right; the rotations were inverted (U1 had
    270 where it needs 90, U2 the reverse). The old DRC's "4 copper-edge corner
    artifacts" were this. Every discrete had been placed around the intended pad
    grid, so only the two rotations needed correcting.
    Layout is now scripted and idempotent rather than hand-edited:
    - place.py — placement table, outline, 4x M3 holes, silkscreen, mirrored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
    [kbdrelay-carrier.kicad_pcb]
2026-08-22 feat(pcb): fab outputs, purchasing BOM and BUILD.md (T-006)
    Adds everything needed to actually make one:
    - fab/print/bottom-copper-MIRRORED-toner.pdf — 1:1 home-etch artwork
    - fab/print/{bottom-copper-asviewed,drill-guide,assembly-top-silk}.pdf
    - fab/gerbers/ — standard Gerbers + Excellon drill and drill map
    - BOM.md — adds a purchasing table (Line#, Qty per P/N, RefDes, P/N,
    description, package, type). All 13 lines are through-hole; the only
    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
    [kbdrelay-carrier-B_Cu.gbl, kbdrelay-carrier-B_Cu.gbr, kbdrelay-carrier-B_Mask.gbs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]
2026-08-22 feat(pcb): LCD photoresist exposure artwork for the Mars 4 Ultra
    The .goo in hardware/ shows the intended process is direct photoresist
    exposure on an Elegoo Mars 4 Ultra, not toner transfer, so a 1:1 PDF is the
    wrong artifact. Adds bitmaps at the panel's native 8520x4320 / 18.0 um pitch:
    - white = copper, for negative-acting dry film
    - pad centres solid (--drill-shape-opt 0); KiCad's default plots the drill and
    would etch out each pad centre, leaving a 0.5 mm ring and no bit guide
    - registration computed from the board's sheet origin and verified against the
    plotted outline at 88.09 x 55.10 mm, not eyeballed
    - make_lcd_art.sh regenerates it; BUILD.md documents polarity and the
    handed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
2026-08-22 feat(pcb): widen etch tolerance - 0.5 mm routing / 0.8 mm pour clearance
    Adds --clearance and --zone-clearance to route.py and raises the defaults.
    These are independent: pour clearance is free tolerance (the fill just
    retreats, routing is untouched), while routing clearance costs routability.
    Both 0.5/0.8 still route with zero jumpers and zero real DRC violations, so
    they are the new defaults.
    Measured minimum copper gaps on the rebuilt board: pour 0.80 mm, trace-trace
    0.70 mm, trace-pad 0.52 mm.
    Documents the real constraint: the tightest feature is the 0.54 mm gap between
    adjacent module pads, which is fixed geometry (2.54 mm pitch - 2.0 mm pads) and
    cannot be improved by any clearance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
    [kbdrelay-carrier-B_Cu.gbl, kbdrelay-carrier-B_Mask.gbs, kbdrelay-carrier-Edge_Cuts.gm1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]
2026-08-22 docs(pcb): bridge-risk map for hand etching + capture exposure profile
    Adds bridge_risk.py, which reports every pad pair under a threshold together
    with what a bridge there would actually cost. The useful framing for a
    hand-etched board is not gap width but how many tight gaps exist and which
    ones matter.
    Result: all 32 of the tightest gaps (0.54 mm) are between adjacent module
    pins, but only 9 matter electrically — the rest neighbour pins that are
    unconnected on the carrier, where a bridge is harmless. BUILD.md now lists
    those nine as a pre-power meter checklist.
    Worth noting: U2.1 (the TGT module's 5 V pin) is unconnected on the carrier,
    so a bridge to U2.2/GND shorts nothing on a bare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
    [kbdrelay-carrier-B_Cu.gbr, kbdrelay-carrier-B_Mask.gbr, kbdrelay-carrier-B_Paste.gbr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]
2026-08-22 chore(pcb): one canonical home for fab outputs
    The KiCad GUI writes exports next to the project file by default, which had
    created a second, stale copy of the Gerbers and drill files alongside the
    canonical set in fab/. That is precisely how someone etches the wrong artwork
    three months from now.
    - removes the duplicates from hardware/pcb-carrier/kbdrelay-carrier/
    - sets the project's plot output directory to ../fab/gerbers/ so the GUI
    defaults to the right place (verified it survives route.py rewriting the
    board file)
    - gitignores the old location so a stray export cannot be committed again
    - documents the layout in BUILD.md: fab/gerbers, fab/print, fab/lcd
    Fab outputs regenerated fro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
    [kbdrelay-carrier-B_Cu.gbl, kbdrelay-carrier-B_Cu.gbr, kbdrelay-carrier-B_Mask.gbr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]
2026-08-22 chore: ignore KiCad reports, Freerouting round-trips, 3D exports, py caches
    Rounds out the ignore list with generated formats we have not produced yet but
    will: DRC/ERC .rpt, netlist .net, Freerouting .dsn/.ses, 3D .step/.wrl, packaged
    fab .zip, and Python caches from the layout scripts.
    Deliberately NOT ignored, since these are reviewed deliverables rather than
    noise: everything under hardware/pcb-carrier/fab/ (Gerbers, drill, 1:1 PDFs, LCD
    bitmaps), the preview render, and PCB_Exposure_40s.goo which documents the
    working exposure recipe.
    (Lock files were already covered by the existing *.lck rule.)
2026-08-22 spec(pcb): requirements amendment - drop the LED, add etch and stock-size limits
    Approved amendment to the pcb-carrier-board requirements:
    - FR-032 WITHDRAWN: the power-good LED (D2 + R12) is redundant now that each
    module's onboard WS2812 shows status, and removing it deletes two parts, four
    holes and several tight copper features from the board's most congested
    corner. Accepted cost recorded: no bare-board power indication, so the T-007
    rail check becomes meter-only (a meter reports the actual voltage the
    procedure needs anyway).
    - NFR-007 added: minimum copper gap >= 0.8 mm anywhere, including between
    adjacent module pins. Where 2.54 mm pitch cannot meet that with round pads,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
2026-08-23 feat(pcb): hand-routed test2 board - min gap 0.54 -> 0.605 mm, zero jumpers
    Captures the hand-routed carrier (kbdrelay-carrier-test2), which is now the
    best artifact we have. It beats the script-generated board on every axis that
    matters for home etching:
    scripted test2 (hand)
    signal traces 0.7 mm 1.0 mm
    wire jumpers 0-2 0
    pour clearance 0.8 mm 1.4 mm
    min copper gap 0.52 mm 0.605 mm
    How it got there, in order of impact:
    - module pads 2.0 mm -> 1.70 mm round: turns 36 pad-to-pad gaps from 0.54 mm
    into 0.84 mm and, because pads only shrink, improves trace-to-pad gaps too
    without di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
    [kbdrelay-carrier-test2.kicad_pcb]
2026-08-23 chore(pcb): clear fab/, derive LCD crop from the board, document refill trap
    fab/ is emptied: it held two naming conventions from two different exports
    (GUI .gbr and CLI protel-style), which is the stale-artwork trap in a new
    outfit. Everything there is regenerable; user is regenerating from test2.
    make_lcd_art.sh now takes a board path and derives the crop window from the
    real Edge.Cuts bounding box instead of hardcoded pixel offsets, so it follows
    the board instead of silently mis-registering if the outline moves.
    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
    [kbdrelay-carrier-B_Cu.gbl, kbdrelay-carrier-B_Mask.gbs, kbdrelay-carrier-Edge_Cuts.gm1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]
2026-08-28 Working 0.1 board
    [kbdrelay-carrier-test2-B_Cu.gbr, kbdrelay-carrier-test2-B_Mask.gbr, kbdrelay-carrier-test2-B_Paste.gbr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]
2026-08-28 chore(pcb): close out v0.1 as the board of record, retire the drift
    v0.1 shipped and was hardware-verified, but the repo still described a
    board that was never fabricated. Freeze v0.1 as an auditable baseline
    before any v0.2 work starts.
    Promote the shipped board to a versioned name
    kbdrelay-carrier-test2.{kicad_pcb,kicad_pro} -> -v0.1.*, plus the
    as-etched Gerbers. The board of record was called "test2" while a
    stale, DRC-failing layout held the canonical name. Tag v0.1-board
    preserves the as-etched filenames and bytes.
    Backfill T-005 with real evidence (was unchecked despite a working board)
    DRC: 0 violations, stable across a pcbnew normalization pass.
    ERC: 0 violations. Trac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
    [kbdrelay-carrier-v0.1-B_Cu.gbr, kbdrelay-carrier-v0.1-B_Mask.gbr, kbdrelay-carrier-v0.1-B_Paste.gbr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]
2026-08-28 docs(pcb): record F-8 (Schottky Vf margin) as accepted-unmeasured
    VBUS was never metered on v0.1. Carrying the series Schottky forward -- a
    THT logic-level P-FET is unsourceable -- but logging it as an accepted
    risk, not a closed question: 'no odd behaviour observed' is not a margin
    measurement, and the failure mode is a future hungrier keyboard.
    Notes the two no-respin escape hatches: the D1 footprint is DO-201AD /
    12.70 mm specifically so an SB540/SB560 drops in at ~half the Vf (and
    retrofits to the existing board), plus the already-documented 5.1-5.25 V
    feed. Breadboarding an ideal-diode alternative is parked, not rejected.
2026-08-29 spec(pcb): open pcb-carrier-v0-2, requirements approved
    Clean-sheet redesign of the carrier board. v0.1 is closed and frozen at
    tag v0.1-board; nothing from its netlist or layout is inherited.
    Brainstorm gate established the boundaries: designed for third parties to
    build, fabbed by PCBWay 2-layer 1oz, THT-only discretes orderable from a
    single distributor, barrel-jack input, 3D-printed case that adapts to the
    board rather than constraining it. The S3-Zero modules, their pin mapping
    and the v1 firmware are fixed -- the board adapts to firmware.
    Two hard constraints found during brainstorm and recorded as DC-002:
    the S3-Zero exposes only 18 pins, with no GPIO19/20 (native USB D+/D-)
    and no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
    [kbdrelay-carrier-v0.1-BOM.csv]
2026-08-30 spec(pcb): v0.2 design draft + requirements amendment A-001
    Requirements (re-approved after amendment A-001)
    NFR-003 reframed: compactness is now the active goal, with 100x100mm
    kept only as PCBWay's prototype pricing bracket and expected to be
    non-binding. NFR-016 added as its counterweight -- the board must stay
    hand-assemblable, with iron access to every joint with neighbours
    already fitted. Without that, "compact" has nothing pulling against it
    and layout crowds parts until soldering is miserable; v0.1 already did
    this once, putting a mounting hole so close to C1 that BUILD.md had to
    specify a low-profile screw. AC-15 verifies it on the assembled board,
    not in CAD -- th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
2026-08-30 spec(pcb): v0.2 design approved
    Both open items accepted knowingly rather than resolved:
    1. The crowbar fails safe by dynamics, not by construction. A series
    diode blocks reverse current outright; the crowbar relies on F1
    tripping. Against a current-limited supply F1 may never trip, leaving
    D1 forward-biased and dissipating -- nothing powered, nothing damaged,
    but a stuck state rather than a clean cutoff. Safe in every case; only
    the mechanism is less absolute than v0.1's.
    2. ~0.255 V of the FR-018 budget is left for the module's internal
    VDD-to-VBUS drop, which has never been measured. If it exceeds that,
    the only fallbacks are the Littelfuse PPTC (+0.055 V) or a supp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
2026-09-19 fix(spi): drive CS open-drain so an unpowered peer can't be back-fed
    With KBD powered and TGT unpowered, TGT would not boot: plugging it in
    left it dead until both boards were power-cycled. The real deployment
    hits this order every time (the Amiga is switched on while KBD's supply
    is already live), so it was not just a bench artifact.
    Root cause: series resistors limit backfeed current but do not block the
    DC path into an unpowered peer's ESD clamps. Of the five link signals CS
    is the only one that idles HIGH, so it injects continuously; SCK and MOSI
    idle low and only inject for the ~384us a frame is in flight. Measured on
    the v0.1 board: KBD powered, TGT unplugged, TGT's 3V3 sat at 1.68V,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
    [main.c]
2026-09-19 docs: record the measured reverse path and the rejected bleeder
    TGT powered / KBD off leaves KBD's 3V3 floating at 0.9-1.1 V through
    TGT's CS pull-up. Lifting CS collapses it, confirming CS is the only
    path in this direction too. The current is 2-3x what a nominal 45k
    internal pull-up should deliver, so the S3's pull-up is well below
    nominal on these parts.
    Verified harmless on a real Amiga 1200: cycling KBD's 5V from the
    pre-charged state booted and linked 5/5, and cycling the Amiga 5/5.
    Also records two negative results so they are not repeated:
    - 10k bleeders from 3V3 to GND did NOT move the voltage (source is
    stiffer than modelled). Removed. Fix the source, not the sink.
    - In-circuit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
